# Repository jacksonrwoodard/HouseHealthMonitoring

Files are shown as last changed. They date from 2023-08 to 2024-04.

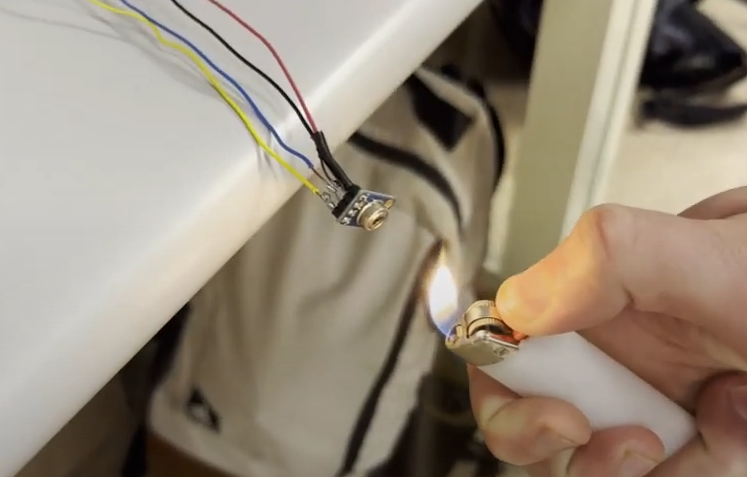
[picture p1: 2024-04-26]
Documentation/Images/Fire/Fire_Test_Open_Flame.jpg

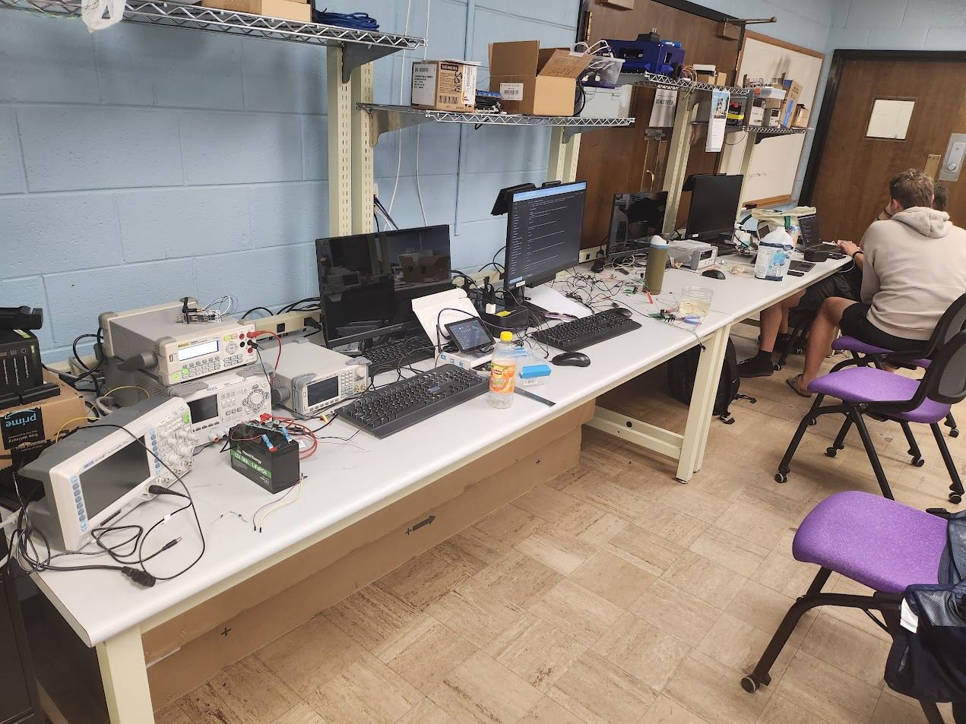
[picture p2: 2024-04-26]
Documentation/Images/Communication/Communication_Test_1.png

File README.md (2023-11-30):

# Preserve Home Pro (PHP)
## Executive Summary

Houses face many types of issues like gas leaks, fires, floods, and mold, which cause damage to the house leading to a decrease in value. Unlike a smartphone or a modern car, current house constructions lack a mechanism to detect and monitor this information. This information, such as knowing if water damage has occurred, could improve the value of the house by proving that issues have not occurred or were taken care of quickly by the homeowner. To detect and monitor all of these problems, this project proposes a collection of sensors and a head unit, called Preserve Home Pro. The goal of the system is to measure, record, and display important active and historical data, giving a homeowner valuable information to help maintain and protect the value of their home. The Preserve Home Pro will be designed as a semi-permanent system that will last for up to thirty years. The system will also communicate information through a closed network without requiring the Internet. Combining these concepts, this project proposes an advanced solution to house health monitoring.

## Capabilities

Detailed capabilities for this project are described in the [Signoffs](https://github.com/jacksonrwoodard/HouseHealthMonitoring/tree/main/Documentation/Signoffs) section of this repository. Each signoff includes the function of the subsystem, constraints, buildable schematics, analysis, and bill of materials. The following bullet points detail the current expectations of the house health monitoring system.
- The Head Unit subsystem expects to receive serial data from the communication receiver and implement a user friendly interface that displays historical and active data from each sensor module.
- The Communication subsystem will allow the sensors' microcontroller to send data wirelessly to the head unit's microcontroller through the Zigbee protocol.
- The Power subsystem will supply power functionality for each subsystem. Each subsystem will be hard-wired into the house with each sensor module having an uninteruptable power supply (UPS) to power them when the electricty in the home goes out. All head unit and communication functionality will be disabled while the power is out to ensure maximum battery lifetime.
- The Mold subsystem will read temperature and humidity levels at its respective sensor in order to detect if mold like conditions are present in a home.
- The Fire subsytem will read specific temperature levels to detect whether a fire is present or not in a room.
- The Gas subsystem will read parts per million (ppm) levels to determine if gas is present in a room and specifiy which gas it is.
- The Flood subsytem will read water levels based on resistivity to detect any amounts of water present in the area.
- Each sensor module will serially send data to a local microcontroller so that it can send the data to the head unit for computation and storage.

## Salient Outcomes

Projects often have some outcomes that are more interesting than others. Here, highlight those things that you found interesting!

(Coming Spring 2024!)

## Project Demonstration & Images

Give a link to a video of the project being demonstrated. The video should be hosted on the capstone youtube.

Below the video link show some well-taken, appropriately sized images of the project.

(Coming Spring 2024!)

## About Us

### Team

[Jackson Woodard](https://www.linkedin.com/in/jacksonrwoodard/) is currently pursuing a degree in Electrical Engineering with a minor in Computer Science at Tennessee Technological University. His academic focus lies in the field of Programmable Logic Controllers (PLC) and Control Systems. In the context of the project, Jackson has been assigned the responsibility of developing a Fire Module designed to detect potential fire occurrences within a designated space. He is also helping design the 3D models for all the subsystems for the project. 

[Cole Cooper](https://www.linkedin.com/in/cole-cooper-78063520b/) is a student of Electrical Engineering enrolled at Tennessee Technological University in Cookeville. He has an academic interest in following the development and sustainment of power systems, microcontrollers, and communication protocols to name a few. Cole's role in this project is the development of the head unit and the communications system between the head unit and the sensor modules.

[Dylan Robbins](https://www.linkedin.com/in/dylan-robbins-51b933256/) is a student currently pursuing a bachelor's degree in Computer Engineering at Tennessee Technological University. His academic interests are focused in Embedded Systems, microcontrollers, and computer programming. Dylan's role in the project is to develop a mold sensing module and design it to detect any mold like conditions in a home. He is also responsible in assisting in any programminng of the sensors and data computations for the system.

[Nate Campbell](https://www.linkedin.com/in/nathaniel-campbell-0b24a2225) is a dedicated Electrical Engineering student enrolled at Tennessee Technological University. His academic focus revolves around Power Systems and Programmable Logic Controllers (PLC). Within the current project, Nathaniel assumes a pivotal role, primarily concentrating on the water sensor aspect and actively contributing to the development of the Uninterruptible Power Supply (UPS) for the overall power system.

[Luke Carson](https://www.linkedin.com/in/luke-carson/) is an Electrical Engineering at Tennessee Technological University with a minor in Mathematics. His primary area of interest lies in power systems, including power generation, transmission, and distribution. As part of a project, Luke is responsible for designing the gas module for the Preserve Home Pro system. The module will be used to detect the presence of propane, carbon monoxide, and ammonia.

### Faculty Supervisor

[Jesse Roberts, M.S.](https://www.tntech.edu/directory/engineering/faculty/jesse-roberts.php) is a professor at Tennessee Technological University. He has received both a Bachelor's and Master's degree in Electrical Engineering at Tennessee Technological University. He is currently pursuing a Doctorate of Philosophy in Computer Science at Vanderbilt University.

### Stakeholders

The customer and major stakeholder for the project is any home owner wanting to monitor and maintain their home's health. This system can be installed in any pre-existing or newly built home to display active and historical data pertaining to the specific sensing modules. Home owners are majorly impacted by this system because this system will physically be installed into their home and will assist inspections of areas and things that might be hard to detect will human senses. One major internal stakeholder for this project is the project supervisor, Jesse Roberts. He has given a majority of the feedback to help further the design process. One major external stakeholder for this project is insurance companies, or more specifically, Wes Harris from State Farm. He has provided valuable feedback on how the project affects not only homeowners but also insurance agencies. With this house health monitoring system being installed into homes, home owners could potentially get discounts on their home insurance since issues will be detected before they are major issues as well as potentially raising the value of their home.

### Recognitions

The team would like to thank the ECE Department at Tennessee Technological University for all the assistance needed in the design process. The team would also like to thank Jesse Roberts for all the assistance that he has given throughout the entire Capstone Project. Finally, the team would like to thank one of the external stakeholders, Wes Harris from State Farm, for answering any questions and providing the team with useful information to further advance the project.

## Repo Organization

### [Reports](/Reports)

The [Project Propsal](https://github.com/jacksonrwoodard/HouseHealthMonitoring/blob/main/Reports/Project%20Proposal/Project%20Proposal%20V2.pdf) report provides information about what the project problem is and the proposed solution.

The [Conceptual Design and Planning](https://github.com/jacksonrwoodard/HouseHealthMonitoring/blob/main/Reports/Conceptual%20Design%20%26%20Planning/Conceptual%20Design%20Final.pdf) report provides all specifications and constraints that the House Health Monitoring project must follow. The report includes all standards and regulations that will be followed during the project.

The [Experimentation](/Reports/Experimentation) report includes (will be finished later)

The [Poster](/Reports/Poster) shows (will be finished later)

The [Final Report](/Reports/Final_Presentation) includes (will be finished later)

The [Lessons Learned](/Reports/Lessons_Learned_&_Acquired_Skills) files show the lessons the team learned throughout the project process. 

### [Documentation](/Documentation)

All documentation for the project is included in the folder listed above. There are folders for 3D Models, Electrical, Images, Meeting Minutes, and Signoffs. All folders can be found in the documentation folder. 

The [Signoffs](/Documentation/Signoffs) folder has all of the approved detailed designs. The designs met all specifications and constraints for each subsystem. 

The [Meeting Minutes](https://github.com/jacksonrwoodard/HouseHealthMonitoring/tree/main/Documentation/Meeting%20Minutes) folder contains detailed minutes for each team meeting that occurred throughout the project process. Reading these files will provide you will knowledge of how the team advanced week to week.

### Software

All software used in the project will be located in this directory. For each system, a folder will be created that contains the relevant code with a readme file explaining the process of installing, executing, and testing the code.

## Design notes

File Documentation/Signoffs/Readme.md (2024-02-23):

## Signoffs

Listed below are all of the team's completed signoffs:

- [Communication Signoff](https://github.com/jacksonrwoodard/HouseHealthMonitoring/blob/main/Documentation/Signoffs/php-communication-signoff.md)
- [Fire Module Signoff](https://github.com/jacksonrwoodard/HouseHealthMonitoring/blob/main/Documentation/Signoffs/jacksonwoodard-fire-signoff.md)
- [Mold Module Signoff](https://github.com/jacksonrwoodard/HouseHealthMonitoring/blob/main/Documentation/Signoffs/dylanrobbins-mold-signoff.md)
- [Headunit Module Signoff](https://github.com/jacksonrwoodard/HouseHealthMonitoring/blob/main/Documentation/Signoffs/php_headunit_signoff.md)
- [Gas Module Signoff](https://github.com/jacksonrwoodard/HouseHealthMonitoring/blob/main/Documentation/Signoffs/lukecarson-gas-signoff.md)
- [Flood Module Signoff](https://github.com/jacksonrwoodard/HouseHealthMonitoring/blob/main/Documentation/Signoffs/natecampbell-flood-signoff.md)
- [Power Module Signoff](https://github.com/jacksonrwoodard/HouseHealthMonitoring/blob/main/Documentation/Signoffs/colecooper-power-signoff.md)

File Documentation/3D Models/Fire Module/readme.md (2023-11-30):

# Fire Module 3D Model

Shown in this file is the completed and printable 3D Model of the enclosure that will be used for the Fire Module.

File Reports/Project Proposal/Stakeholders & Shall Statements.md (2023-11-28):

## Stakeholders
  - Interior Stakeholders
    - Project Team
    - Project Supervisor (Jesse Roberts)
    - Funding (ECE Department)

  - External Stakeholders
    - Home Owners
    - Landlords
    - Insurance Companies

## Shall Statements

1) The Head unit shall know what sensor is sending data to
it, the sensor’s location, and be able to differentiate from
other sensors. This originated from the team supervisor.
2) The Head unit shall be able to display and log active
and historical data from sensors. This originated from
the project team and team supervisor.
3) Head unit shall be able to detect if the fire module
temperature is at 176 degrees Fahrenheit or higher and
display a warning [4]. This originated from the project
team based on the ignition temperature of drywall.
4) The Head unit shall be able to receive data from the
water module to display a warning if water is present and
the total water depth. This originated from the project
team.
5) Head unit shall receive data from the gas module and
follow OSHA standards for ammonia, propane, and carbon oxides (50 ppm, 1000 ppm, and 50 ppm respectively
over an eight-hour window) [5]. This originated from the
OSHA standards for the project.
6) Head unit shall be able to interpret, from the received
data, that mold could form if the humidity levels exceed
50% and temperatures range between 55 degrees and 85
degrees Fahrenheit for a minimum of two days [6]. This
originated from the project team based on the conditions
in which mold can grow.
7) Head unit shall be able to receive the sensor name,
number, data type, and raw data. This originated from
the team supervisor.
8) System shall be primarily powered from the house’s 120
V power supply. This originated from the project team.
9) Shall be a semi-permanent system that will last for up to
thirty years. This originated from the team supervisor.
10) Shall have a backup power system that will allow the
system to function in case of a primary power outage
for up to two continuous weeks. This originated from
both a standard and the team supervisor.
11) Shall fully function without regularly changing sensors
or head unit batteries. This originated from all external
stakeholders and the team supervisor.
12) Sensor modules shall not be placed in a way where they
cannot wirelessly communicate with the system. This
originated from the project team and broader implications.
13) Modules shall not be a distraction for a homeowner, and
not be directly visible. This originated from all external
stakeholders and the team supervisor.
14) The Water module shall be able to detect multiple water
levels and determine if water is present. This originated
from the project team.
15) The Mold module shall be able to detect the current
temperatures and humidity levels in an area and send it
to the head unit. This originated from the project team.
16) The Gas module shall be able to detect ammonia,
propane, and carbon oxide. This originated from the
project team and the insurance companies.
17) The Fire module shall be able to detect the temperature
of the sensor and send the data to the head unit. This
originated from the project team.
18) System shall not require an internet connection to work
and communicate with the head unit and sensors. This
originated from homeowners, insurance agencies, and
the team supervisor.
19) Sensor communication shall send the sensor name, number, data type, and raw data to the head unit. This
originated from the project team.
20) System shall not collect additional data that is not
required for sensor functionality. This originated from
all internal and external stakeholders and from broader
implications.
21) System shall follow all IEEE Code of Ethics and common standards. This originated from the IEEE Code of
Ethics.

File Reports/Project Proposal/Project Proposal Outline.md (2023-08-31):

Project Proposal Outline
================================

- Abstract (Elevator Pitch)
- Keywords

## Introduction
- Objective/Goal
- Why is this important?
- Solution

## Formulating the Problem
- Background Information
  - Includes head unit & all 5 types of sensors we plan to use
    - Flood Sensor (Nate)
    - Mold/Moisture Sensor (Dylan)
    - Heat/Fire Sensor (Jackson)
    - Gas/Smoke Sensor (Luke)
    - Electrical Sensor (Cole)
    - Termite Sensor?
- Constrants & Specifications
  - Standards
  - External Effects on Life
- Discovered Solutions
  - Hardware & why we are going to use it
  - Researching solutions that have already been solved
- Summerizing the Problem
   - What makes the project different/better from other solutions?
  
## Proposed Solution
  - Unknowns, Obstacles, Implications, and Necessary Experiments
  - Measurements of Success
    - Explain experiments that we are going to do and what we will classify it as a success.
  - Responsibiliies as an Engineer

## Resources
  - Budget Proposal
  - Sofware, equipment, materials
  - Personnel
  - Timeline
    - Gantt Chart
   
## Refrences

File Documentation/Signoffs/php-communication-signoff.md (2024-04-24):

# Communication Module Signoff

## Subsystem Function
The function of the communication subsystem is to act as a transmitter for each of the sensor modules and a receiver for the head unit. The function of the transmitter is to send the sensor name, data type, sensor number, and sensor data. The function of the receiver is to receive all of the data from the sensor modules and make the received information available to the processor. 

TransmitterCommunication

RecieverCommunication

## Constraints
| No. | Constraints | Origin |
| --- | --- | --- |
|  1  | System shall not require an internet connection to work and communicate with the head unit and sensors | Home Owners, Insurance Agencies, & Team Supervisor |
|  2  | At least one sensor shall be placed within 200ft of the head unit. | Project Team |
|  3  | Sensors shall be within 32ft from each other for every sensor outside of 200ft of the head unit. | Project Team |
|  4  | Sensor communication shall send the sensor name, number, data type, and raw data to the head unit. | Project Team |
|  5  | ESP32 shall be able to send a minimum of 128 bits (2 packets) at a transmission rate of at most 250 Kbps on a 2.4 GHz frequency. | Project Team & Standards|
|  6  | The head unit shall, at minimum, receive data every 24 hours, when the data from the sensor reaches a critical level, or when the user requests the data. | Project Team |

<sup>1</sup> In order for the system to not require an internet connection, the system will be designed to work on a Personal Area Network (PAN). In order to achieve this, the Zigbee communication protocol will be used.

<sup>2</sup> In order for the system to work properly all of the sensors have to be able to communicate with the head unit. At least one sensor has to be within 200ft of the head unit because the XB24's maximum range allows for 200ft of indoor communication. Indoor means through the interior walls of a house.

<sup>3</sup> The sensors have to be placed within 32ft of each other for the minimum transmission and reception range of the Zigbee-compliant devices.

<sup>4</sup> The head unit needs to know the sensor information to be able to organize the data of each sensor. Knowing this allows the information to be more easily displayed to the user.

<sup>5</sup> In order to meet Zigbee specifications and IEEE 802.15.4 standards, it is required to have a transmission rate of at most 250 Kbps on a 2.4 GHz frequency. Zigbee networks are secured by 128-bit symmetric encryption to meet Zigbee specifications, so 128 bits have to be sent to the head unit per transmission.

<sup>6</sup> In order to save power, the system is designed to only send data to the head unit at least once every 24 hours. The ESP32-H2 will store the data received from the sensor and send the stored data to the head unit when requested or when the data has reached the specific limit that causes a threat. The user will have the option to request for the data and if the data is requested the ESP32 will send the data over to the head unit for the user to see. With this constraint, power will be saved significantly allowing the system to have the ability to work off of battery power for a minimum of two weeks.

## Buildable Schematic
#### Head Unit Reciever from Manufacturer
Reciever

The picture shown above is the XB24CAWIT-001, the schematic shows an in-depth design of the receiver.
#### Sensor Module Transmitters from Manufacturer
 Transmitter
 
The picture shown above is the ESP32-H2, the schematic shows an in-depth design of the transmitter.

#### Third-Party Buildable Schematic

CommunicationSchematic

This is a third-party buildable schematic to show connections and communications from the sensor modules and the head unit. The pins labeled DOUT (TX) and DIN (RX) on the XB24 are the UART pins [4]. The XB24 will use these pins to transmit and receive information to and from the head unit using serial UART communication [4]. The ESP32-H2 has many peripherals that can be used through most of the GPIO pins [1]. The use of these GPIO pins will vary from sensor to sensor depending on the required pinouts to serially send and receive information between the ESP32-H2 and sensor. Communication between each ESP32-H2 and the XB24 will be wireless using and following Zigbee protocols.

## Analysis

<sup>1</sup> The ESP32-H2 is able to communicate via Zigbee protocols [1]. Zigbee protocols allow for the formation of a mesh network, allowing the system the work for any size house without an existing internet connection [2]. The ESP32-H2 has a built-in 2.4 GHz receiver and transmitter that will form a mesh network to ensure that all sensors will be able to communicate with the head unit [1]. Zigbee is designed to create a personal area network (PAN), which would not require the system to have to connect to an internet connection [3]. Zigbee devices are either preconfigured with a PAN ID to join, or they can discover nearby networks and select a PAN ID network to join [3]. This allows any Zigbee device to connect to each other as long as the PAN ID is in a discoverable range. 

<sup>2</sup> The head unit is not able to communicate with Zigbee devices natively, so a Zigbee-capable transmitter and receiver are necessary for proper function. The XB24 is able to communicate via Zigbee protocols [4]. This Zigbee module allows direct connectivity to an Arduino or related board. It will also allow the system to extend its range up to 200ft indoors, giving it the ability to reach the sensors in a house [4]. If a sensor is placed outside of the 200ft range, then a mesh network would be incorporated into that system.

<sup>3</sup> The ESP32-H2 has the capability to transmit data at a minimum of 32ft [5]. For a mesh network to be created, there must be a sensor within 200ft of the head unit and a sensor within 32ft of that sensor. So, as long as each sensor module is placed within 32ft of one another, a mesh network can be used [5]. 

<sup>4</sup> Zigbee protocol requires a minimum of 128 bits to be sent during transmission [2]. Each sensor module will have a unique 16-bit PAN ID allowing the information to be differentiated from one another [3]. The PAN ID will be sent to the head unit allowing it to act as an identifier to determine which sensor is sending data. The remaining 112 bits of the transmission will be used for the data type, raw data, and encryption. All of the sensors being used will not require more than 24 bits to send the raw data, so with the amount of remaining bits, this would be possible. The data type will also not require more than 24 bits, so this would be possible. This information will be used for showing the live and stored data from the modules. 

<sup>5</sup> According to the ESP32-H2 datasheet, the ESP32-H2 is designed to follow all Zigbee specifications [1]. This means that the ESP32-H2 will be able to send a minimum of 128 bits (2 packets) at a transmission rate of at most 250 Kbps on a 2.4 GHz frequency. Each module has 320 kB SRAM, meaning each module can hold up to 2,621,440 bits in a given moment for local storage and transmission information. In a setting of 100 sensor modules if a singular module held onto the transmission data from each module would take up 12800 bits leaving 2,608,640 bits free in the ESP32 H2’s SRAM for other operations like continual data reading from the attached sensor. The ESP32 H2 will be sufficient for receiving all communications from other devices in the network.

<sup>6</sup> In order to preserve power, the ESP32 will store the data that the sensors read and send the data to the head unit every 24 hours. The ESP32 uses significantly more power to transmit or receive data than just reading data from the sensor. Opting to store data on the ESP32 and send it to the head unit every 24 hours, will cut down power consumption allowing for the 30-year life expectancy. The head unit will still receive all sensor reading data, but it will only send the data, at minimum, once every 24 hours to reduce power consumption. The ESP32 will also send the data to the head unit if the sensor data reaches the critical level that is specified in the code on the ESP32. The critical level will depend on each separate sensor module. The head unit will have the ability for the user to request the current data from the sensors. If the user requests the data, the ESP32 will send the data that is currently stored on the ESP32 to the head unit, showing the user the active data. The largest amount of data that any sensor module will use is 1 packet because each sensor has a unique 16-bit PAN ID and data reading will not need more than 48 bits with the sensors that are being used in the system. The ESP32 has 4MB ROM of storage allowing it to store the sensor module data for up to 24 hours [5]. There are 32,000,000 bits in 4MB, and at 64 bits per packet, each ESP can store 500,000 readings at a time. There are 86,400 seconds in 24 hours, so if the sensors were to store data every second in a 24-hour period, this would still be possible.

## Bill of Materials (BOM)
| DEVICE | Quantity | Price Per Unit | Total Price | Overall Total |
| --- | --- | --- | --- | ----- |
| ESP32-H2-DEVKITM-1-N4 | 3 | $10.00 | $30.00 | |
| SONOFF Zigbee 3.0 USB Dongle Plus | 1 | $21.99 | $21.99 | $51.99 |

## References
[1] Espressif Systems, “ESP32-H2 - Espressif Systems,” Adafruit, https://www.espressif.com/sites/default/files/documentation/esp32-h2_datasheet_en.pdf (accessed Oct. 24, 2023). 

[2] “Discover Zigbee protocol 3.0,” Discover Zigbee Protocol 3.0 | Digi International, https://www.digi.com/solutions/by-technology/zigbee-wireless-standard (accessed Oct. 24, 2023). 

[3] “PAN ID,” Pan Id, https://www.digi.com/resources/documentation/Digidocs/90002002/Concepts/c_zb_pan_id.htm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,devices%20of%20the%20same%20network. (accessed Oct. 25, 2023). 

[4] “Digi xbee S2C 802.15.4 RF modules Datasheet,” IIoT Devices and Services for M2M Networking, https://www.digi.com/resources/library/data-sheets/ds_xbee-s2c-802-15-4?view=fullscreen (accessed Oct. 24, 2023). 

[5] Reolink, “Zigbee range: You must know the truth,” Reolink, https://reolink.com/blog/zigbee-range/ (accessed Oct. 25, 2023).

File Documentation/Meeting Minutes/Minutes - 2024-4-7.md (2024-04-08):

Opening
The team meeting of Capstone I Team 4 was held at 1:00 PM on April 1, 2024 in Brown Hall in room 408.

Present
Cole Cooper, Secretary
Dylan Robbins, Team Member
Jackson Woodard, Team Lead
Luke Carson, Team Member
Nate Campbell, Team Member

Approval of Agenda
This meeting was approved by Jackson Woodard.

Business From Previous Meeting
The first order of business is the continuation of work on additional module communication with the head-unit.

The next order of business is comparing the existing function of the overall system with the determined success and constraint metrics.

New Business 
No new business this week.

Additions to the Agenda
Each member is determining and preparing their measures of success and experimentation.

Jackson is continuing to add more wireless communication between sensor modules and the headunit. 

Nate has figured out how to allow for analog pin readouts to be read and transferred wirelessly to the head-unit. 

Luke is working on re-configuring Nate’s code to work with the gas sensor. 

Dylan and Jackson are compiling a code in order to get the temperature sensors from the mold and fire modules functioning. 
Cole is working on setting up the initial documentation for experimentation in the github. 

Agenda for Next Meeting
The first order of business is the continuation of work on additional module communication with the head-unit.

The next order of business is comparing the existing function of the overall system with the determined success and constraint metrics.

Adjournment 
Meeting was adjourned at 3:00 PM by Jackson Woodard. With planning of meeting again on April 15, 2024 at 1:00 PM.

Minutes Submitted by: Cole Cooper
Approved by: Jackson Woodard

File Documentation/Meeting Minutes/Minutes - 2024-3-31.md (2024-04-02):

Opening
The team meeting of Capstone I Team 4 was held at 1:00 PM on April 1, 2024 in Brown Hall in room 408.

Present
Cole Cooper, Secretary
Dylan Robbins, Team Member
Jackson Woodard, Team Lead
Nate Campbell, Team Member

Absent
Luke Carson, Team Member

Approval of Agenda
This meeting was approved by Jackson Woodard.

Business From Previous Meeting
Finish any additional sections of additional functionality needed.

New Business 
No new business this week.

Additions to the Agenda
Cole, Dylan, and Luke were able to successfully set the headunit to be able to receive and display the information generated by the sensor modules.

Jackson and Nate are fine tuning a new code to allow for more sensor-modules to head-unit communication. This step has been extremely time intensive due to a lack of example ESP32 H2 example codes. This lack of example codes is most likely due to the ESP32 H2 being so new to the market. 

Agenda for Next Meeting
The first order of business is the continuation of work on additional module communication with the head-unit.

The next order of business is comparing the existing function of the overall system with the determined success and constraint metrics.

Adjournment 
Meeting was adjourned at 3:00 PM by Jackson Woodard. With planning of meeting again on April 8, 2024 at 1:00 PM.

Minutes Submitted by: Cole Cooper
Approved by: Jackson Woodard

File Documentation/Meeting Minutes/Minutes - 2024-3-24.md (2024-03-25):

Opening
The team meeting of Capstone I Team 4 was held at 1:00 PM on March 18, 2024 in Brown Hall in room 408.

Present
No meeting was held this week

Absent
Luke Carson, Team Member
Cole Cooper, Secretary
Dylan Robbins, Team Member
Jackson Woodard, Team Lead
Nate Campbell, Team Member

Approval of Agenda
This meeting was approved by Jackson Woodard.

Business From Previous Meeting
Finish any additional sections of additional functionality needed.

New Business 
No new business this week.

Additions to the Agenda
Cole and Jackson are working on setting up the head-unit to allow for the head-unit to receive and display information from the sensor-modules. As of current, the head-unit has only been able to receive the information, but another computer was needed for reading the received information.

Dylan, Luke and Nate are working on compiling and testing a new code in order to allow for more sensor-modules to head-unit communication.

Agenda for Next Meeting
The first order of business is the continuation of work on additional module communication with the head-unit.

The second order of business is finishing the head-unit’s receive and display functionality.

The final order of business is comparing the existing function of the overall system with the determined success and constraint metrics.

Adjournment 
Meeting was adjourned at 3:00 PM by Jackson Woodard. With planning of meeting again on March 25, 2024 at 1:00 PM.

Minutes Submitted by: Cole Cooper
Approved by: Jackson Woodard

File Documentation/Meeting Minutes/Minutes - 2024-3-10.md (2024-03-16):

Opening
The team meeting of Capstone I Team 4 was held at 1:00 PM on March 4, 2024 in Brown Hall in room 408.

Present
No meeting was held this week

Absent
Luke Carson, Team Member
Cole Cooper, Secretary
Dylan Robbins, Team Member
Jackson Woodard, Team Lead
Nate Campbell, Team Member

Approval of Agenda
This meeting was approved by Jackson Woodard.

Business From Previous Meeting
Finish any additional sections of additional functionality needed.

New Business 
No new business this week.

Additions to the Agenda
Cole has ordered a new USB antenna for use as a receiver from the modules. The XBee s2c was not communicating with the head unit resulting in a new device needed.

Jackson, Dylan, Nate, and Luke are continuing the conversion of code from Arduino’s ESP IDE to Espressif’s ESP IDE. Espressif is the manufacturer of the ESP devices and we have found that wireless communication works better using the Espressif IDE.

Agenda for Next Meeting
Finish any additional sections of additional functionality needed.

Adjournment 
Meeting was adjourned at 6:00 PM by Jackson Woodard. With planning of meeting again on March 18, 2024 at 1:00 PM.

Minutes Submitted by: Cole Cooper
Approved by: Jackson Woodard

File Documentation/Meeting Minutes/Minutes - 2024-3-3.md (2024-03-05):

Opening
The team meeting of Capstone I Team 4 was held at 1:00 PM on March 4, 2024 in Brown Hall in room 408.

Present
Luke Carson, Team Member
Cole Cooper, Secretary
Dylan Robbins, Team Member
Jackson Woodard, Team Lead

Absent
Nate Campbell, Team Member

Approval of Agenda
No new agenda was added for this meeting

Business From Previous Meeting
Dylan has started working on the code to get the mold module to function. This code is not functioning yet. We believe his code will be similar to Jackson’s.

Jackson has started working on the code to get the fire module to function. Through initial attempts this code is functioning with a few errors.

Nate has started working on the code to get the water module to function. This code is functioning and the water sensor is reading and outputting values as expected.

Luke has started working on the code to get the gas module to function. This code is not functioning yet. We believe his code will be similar to Nate’s.

Cole is starting on the setup for the head unit to be able to communicate and store data read from each module.

New Business 
Jackson will record the fire module’s sensor reading accurate temperatures to prove minimal functionality.

Dylan will record the mold module’s temperature and humidity sensor functioning correctly to prove minimal functionality.

Luke will record the gas module’s sensor reading voltage changes from the gas parts per million to prove minimal functionality.

Nate will record the water module’s sensor reading voltage changes from water being in contact with the sensor.

Additions to the Agenda
No additions this week.

Agenda for Next Meeting
Finish any additional sections of additional functionality needed.

Adjournment 
Meeting was adjourned at 6:00 PM by Jackson Woodard. With planning of meeting again on March 11, 2024 at 1:00 PM.

Minutes Submitted by: Cole Cooper
Approved by: Jackson Woodard

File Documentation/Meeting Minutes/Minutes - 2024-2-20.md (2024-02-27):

Opening
The team meeting of Capstone I Team 4 was held at 1:00 PM on February 20, 2024 in Brown Hall in room 408.

Present
Nate Campbell, Team Member
Luke Carson, Team Member
Cole Cooper, Secretary
Dylan Robbins, Team Member
Jackson Woodard, Team Lead

Absent
All members present

Approval of Agenda
No new agenda was added for this meeting

Business From Previous Meeting
Luke was able to add the schematic updates to the gas module in order to get it signed off.

Cole got feedback from Dr. Bhattacharya about what battery type and charging circuit would be best fit for the project. The battery type mentioned is a Lithium Iron Phosphate battery, while the recommended charging circuit is a voltage divider trickle charger. This type of battery will allow for 10 years of use with instant power swap over for continual usage of the sensor modules. 

New Business 
Dylan has started working on the code to get the mold module to function. This code is not functioning yet. We believe his code will be similar to Jackson’s.

Jackson has started working on the code to get the fire module to function. Through initial attempts this code is functioning with a few errors.

Nate has started working on the code to get the water module to function. This code is functioning and the water sensor is reading and outputting values as expected.

Luke has started working on the code to get the gas module to function. This code is not functioning yet. We believe his code will be similar to Nate’s.

Cole is starting on the setup for the head unit to be able to communicate and store data read from each module.

Additions to the Agenda
Cole was able to add the information learned from Dr. Bhattacharya to update the power module in order to get it signed off.

Agenda for Next Meeting
Start team discussion of minimal functionality of this project.

Adjournment 
Meeting was adjourned at 6:00 PM by Jackson Woodard. With planning of meeting again on February 27, 2024 at 1:00 PM.

Minutes Submitted by: Cole Cooper
Approved by: Jackson Woodard

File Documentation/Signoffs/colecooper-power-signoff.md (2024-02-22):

# Power Module Signoff

## Subsystem Function
The power system allows the sensor modules to function properly on power from a house and in case of power outages. In order to safely and reliably maintain the funcion of the sensors, the use of an uninteruptable power supply (UPS) is also necessary.

## Constraints
| No. | Constraints | Origin |
| --- | --- | --- |
|  1  | System shall be primarily powered from the house's 120 Volt power supply. | Project Team |
|  2  | Shall have a backup power system that will allow the system to function in case of primary power outage for up to two continuous weeks. | Project Team & Team Supervisor |
|  3  | Shall fully function without regularly changing sensors or head unit batteries. | All External Stakeholders, & Team Supervisor |

<sup>1</sup> The standard residential voltage is 120 V power in the United States. The power module will need to work with the North American standard in order for the sensor modules and head units to have reliable power access.

<sup>2</sup> The sensor modules should still be functional even when the primary power source is out. In the United States the year of 2021 had multiple record breaking power outages lasting up to two weeks. The modules should still be able to record information while the power is out. 

<sup>3</sup> The ESPs and sensors will be powered through the UPS while the main power source is out, to allow for minimal functionality, until it kicks back on. The UPS will include a charging circuit so that the same batteries can stay in place and be recharged.

## Buildable Schematic
 UPS Circuit Diagram

The power comes from the 15V 2A wall wart that goes through a diode to prevent the eletricity from the battery pack from feeding back into the wall power. The 1 kOhm resistor is used to reduce the amount of amperage that will go to the battery pack allowing for the battery to be charged slowly and not over charge the battery. The other diode is used to provide a low resistance path between the voltage regulator and the battery pack. This enables the ESP32 to be powered if the voltage drops too low. The voltage regulator is used to step down the voltage to output exactly 5V into the ESP32 [1].

## Simulations
UPS Circuit Design (LTSpice)
LTSpice Wall Power Vin
LTSpice Wall Power Vout

The three pictures shown above are the LTSpice simulations showing the voltage going into the voltage regualtor and the voltage going out of the voltage regulator when there is power in the house.

UPS Circuit Design (LTSpice) 0V Wall Power
LTSpice Battery Power Vin
LTSpice Wall Power Vout

The three pictures shown above are the LTSpice simulations showing the voltage going into the voltage regualtor and the voltage going out of the voltage regulator when there is no power in the house.

## Analysis
<sup>1</sup> The Raspberry Pi 4B and the ESP32 H2 DEVKITM-1 both use 5 volt power in for proper operation. The Raspberry Pi 4 power supply is a transformer that converts the 120V AC down to the needed 5V DC to make the microcontrollers work properly. 

<sup>2</sup> The team is creating an uninterruptible power supply (UPS) using diodes, a voltage regulator, a resistor, a 12.8V 9Ah battery, and a 120V AC to 14.6V DC transformer. The circuit diagram shown above is a voltage divider [1]. In a conversation with Dr. Bhattacharya, he said “for charging your system, a voltage or current divider would be the best system.” Using a LiFePO4 battery that has a BMS will prevent over charging from this voltage divider circuit. When running the ESP32-H2 and one sensor, the minimum amount of amp hours needed is 6216 mAh for two weeks. The battery that has been chosen operates at 9Ah which is greater than the 6.216 Ah (6216 mAh) needed, so the system will be able to operate for a minimum of two weeks with the chosen battery. The UPS is designed to charge the battery when the power is on, and when the power is off the battery will be powering the ESP32 and the sensor. 

<sup>3</sup>  After discussion with Dr. Bhattacharya, there is no type of battery that can last for a 30 year life span for our use case. The type of battery that Dr. Bhattacharya recommended is the lithium iron phosphate (LiFePO4) battery. The deep cycle LiFePO4 batteries have a 10 year service life with 2,000+ cycles. The battery we have specified has around 4,000 cycles which is a full charge and discharge each day for over 10 years. The 12.8V 9Ah battery has the power to let the system fully function without the need of standard wall power for over the two-week period needed. The UPS will recharge the battery when the power is on, allowing the backup batteries to have full charge for any time the wall power is lost. The 12.8V 9Ah battery is a LiFePO4, which is being used for longer life span compared to other rechargeable batteries, higher safety factor, and improved discharge and charge efficiency thanks to its integrated battery management system (BMS) [2]. LiFePO4 batteries, like the one we are using, come with a battery management (BMS) that protects the cells within the battery pack from overcharge voltages over 14.6 V DC, over discharge, shorts, over currents, and high temperatures. The BMS and low cycle rate will help ensure this battery stays functional for its full 10 year service life.

## Bill of Materials (BOM)
| DEVICE | PART NUMBER | Quantity | Price Per Unit | Total Price |
| --- | --- | --- | --- | --- |
| Raspberry Pi 4 Power Supply | SC0214 | 3 | $8.00 | $32.00 |
| 14.6V LiFePO4 Battery Charger | TP-30W-1462000 | 1 | $13.59 | $13.59 |
| 1N4001 Diode Pack | 1N4001 | 1 | $4.07 | $4.07 |
| 12.8V 9Ah LiFePO4 Lithium Battery | 3164-PSL-SC-1290F2-ND | 1 | $37.99 | $37.99 |
| L7805CV Voltage Regulator | L7805 | 1 | $8.59 | $8.59 |

## References
[1] J. Smith, “Create your own battery backup power supplies - projects,” All About Circuits, https://www.allaboutcircuits.com/projects/battery-backup-power-supplies/ (accessed Feb. 5, 2024).

[2] SuperB, “The lithium difference,” Benefits of Lithium Iron Phosphate batteries (LiFePO4), https://www.super-b.com/en/lithium-iron-phosphate-batteries/benefits-lithium-batteries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,you%20can%20make%20over%20time. (accessed Feb. 19, 2024).

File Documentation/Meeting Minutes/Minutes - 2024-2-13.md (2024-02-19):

Opening
The team meeting of Capstone I Team 4 was held at 1:00 PM on February 12, 2024 in Brown Hall in room 408.

Present
Nate Campbell, Team Member
Luke Carson, Team Member
Cole Cooper, Secretary
Dylan Robbins, Team Member
Jackson Woodard, Team Lead

Absent
All members present

Approval of Agenda
No new agenda was added for this meeting

Business From Previous Meeting
Cole will reach out to Dr. Bhattacharya over more specific information on batteries that can be used. 

Luke needs to add updates to the schematic to show where the filter that prevents significant interference will go. 

New Business 
No new business was added in this meeting

Additions to the Agenda
Luke was able to add the schematic updates to the gas module in order to get it signed off.

Cole got feedback from Dr. Bhattacharya about what battery type and charging circuit would be best fit for the project. The battery type mentioned is a Lithium Iron Phosphate battery, while the recommended charging circuit is a voltage divider trickle charger. This type of battery will allow for 10 years of use with instant power swap over for continual usage of our sensor modules. 

Agenda for Next Meeting
Start team discussion of minimal functionality of this project.

Adjournment 
Meeting was adjourned at 6:00 PM by Jackson Woodard. With planning of meeting again on February 19, 2024 at 1:00 PM.

Minutes Submitted by: Cole Cooper
Approved by: Jackson Woodard

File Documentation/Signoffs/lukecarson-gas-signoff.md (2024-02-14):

# Gas Module Signoff

## Subsystem Function
The gas module detects three gases that can be found in homes: propane, carbon monoxide, and ammonia. The module collects data on gas concentrations and wirelessly transmits it to the head unit through our wireless communication module. At the head unit, the data undergoes analysis to ensure compliance with OSHA standards for an eight-hour monitoring window. This process provides real-time data and alerts about gas concentrations, helping the system respond to and manage safety or environmental concerns.

Gas Module Block diagram

## Constraints
| No. | Constraints | Origin |
| --- | --- | --- |
|  1  | The Gas module shall be able to detect ammonia, propane, and carbon oxide. | Project  Team, Insurance Agencies|
|  2  | Head unit shall receive data from the gas module and follow OSHA standards for ammonia, propane, and carbon oxides (50 ppm, 1000 ppm, and 50 ppm respectively over an eight-hour window)| OSHA |
|  3  | The Gas module shall send data to headunit every second if the targeted gases are detected | Project Team |
|  4  | The Gas module shall be installed in a central location outside each sleeping area or in the immediate vicinity of the bedrooms, at the maximum of 20 feet | NFPA |
|  5  | The Gas module shall be placed as close as possible to potential gas leak spots | Project Team, Existing Products |
|  6  | The Gas module shall be orientated to where the target gas vapours tend to rise or fall | Project Team, Existing Produts |
|  7  | The Gas module shall not be placed near entrances/disturbances or fresh air vents where concentrations can be diluted | Project Team, Existing Products |
|  8  | The Gas module shall not be placed in bathrooms, garages, kitchens, furnace rooms, extremely dusty or dirty areas | Project Team, Existing Products |
|  9  | The Gas module shall not be placed in areas of the house enviroment where it is colder than -10°C or hotter than 50°C | Manufacturer |
|  10  | The Gas module shall not be placed in areas of the house enviroment where the humidity is more than 95% | Manufacturer |
|  11  | The Gas module shall be protected from unwanted variation of sensor readings due to noise | Project Team |

<sup>1</sup> Preserve Home Pro aims to detect three specific gases commonly known for causing poisoning at home. [1]

<sup>2</sup> To comply with OSHA standards, the gas concentrations monitored by Preserve Home Pro will be checked for an eight-hour period. [2]

<sup>3</sup> Preserve Home Pro will ensure fast response times if there is a adequate amount of gas presence specified in the other constraints in order to prevent harmful effects to the customer.

<sup>4</sup> Preserve Home Pro will follow the guidelines specified in the fourth constraint as per the NFPA standards. [3-4]

<sup>5</sup> To maximize the potential in detecting gas leaks, the gas module will be installed where gas piping is being fed into. [5]

<sup>6</sup> The targeted gases will be placed either near the ceiling or near the floor since each gas is either heavier or lighter than air and flows up or down. [5]

<sup>7</sup> Based on existing product installation manuals, Preserve Home Pro will avoid placing gas sensors in areas where there is a potential disturbance that could affect sensor detection. [3-5]

<sup>8</sup> Based on existing product installation manuals, Preserve Home Pro will avoid placing sensors in environments where there is a likelihood of false positives from other sources. [4]

<sup>9</sup> To meet the manufacturer's work environment, the sensors will not be placed within the specified temperature range.in order to keep functionality for constraints 9 and 10. [6-7]

<sup>10</sup> In order to provide reliable, accurate, and usable data the team will need to implement filtering in order to provide stable sensor readings. [16]

## Buildable Schematic  



Figure 1. This is the schematic of the MQ-9 sensor that is being used on the SRAQ-G014, this sensor targets propane and carbon monoxide. [9]



Figure 2. This is the schematic of the MQ-135 sensor that is being used on the SRAQ-G016, this sensor targets ammonia. [8]

#### Third-Party Buildable Schematic


Figure 3. This the wiring schematic of how the gas sensors will be connected to the each respective ESP32-H2, with the RC Filter in place.

## Analysis

<sup>1</sup> To meet constraints 1 and 2, there will be a need for two sensors to detect the gases Preserve Home Pro is targeting. The SRAQ-G014 will detect the presence and concentration of flammable gases (Propane) and carbon monoxide. The device features the MQ-9 sensing element that is highly sensitive to propane and carbon monoxide and has a detection range of 50-10000 ppm for propane and 10-1000 ppm for carbon monoxide.[6] The SRAQ-G016 is like the SRAQ-G014 but features the MQ-135 sensor whose elements are highly sensitive to ammonia and the detection range is from 10-1000ppm.[7] These ranges are crucial to meet the standards set by OSHA for the eight-hour monitoring window.

The gas module technical parameters show that the module will need a one-time 24-48 hour burn-in time for the sensors to be correctly calibrated and accurate. After that, the pre-heat time will be 30 minutes for the gas module to be calibrated and then the sensor will start collecting accurate data and be checked every second.[6-7]

Since the gas module detects and measures the concentrations of the specified gas ranges using analog voltage levels (within 0-5V), the analog output pins from the gas module will be connected to a 12-bit ADC pin on the ESP32-H2 so the microcontroller can collect and process into meaningful concentration data.[13] The ESP ADC takes data from the range of 0-3.3V, this means Preserve Home Pro will have to incorporate of voltage divider with the gas sensors in order to bring the voltage levels down from 5V to 3.3V in order to record accurate data and not lose any.

Now knowing this, we can use the binary base equation **2<sup>n</sup>**, where n is the number of bits the ADC is using which is 12 bits.[13] From the equation below, the ADC provides 4,096 discrete values within the 0-3.3V range, enabling fine voltage distinctions required for the calculation of ppm measurements. [13-15]

```math
Resolution = 2^n = 2^{12} = 4,096 steps
```

To be able to detect the smallest step size in ppm the ADC provides 4,096 unique values and Preserve Home Pro needs to detect the ppm range of 10-10000ppm for the gas targets.[6-7] [13] 

From the equation below, we can calculate smallest possible difference in values that can be measured compared to a scale of 10 to 10,000. This is calculated by dividing 9,990 (or the range between 10-10,000ppm) by the number of steps, or 9,990/steps. [15]

```math
Smallest-step = \frac{(Maximum-ppm)} {(Resolution)} = \frac{(9,990)} {(4,096)} = 2.439 ppm/step
```

<sup>2</sup> For constraint 3, the sensor will be connected to the communication module powered by an ESP32 microcontroller. As stated in the communication sign-off, the microcontroller has a transmission rate of 250 Kbps and sends two packets of data at a time. The sensor will will output a max value of 4096 or 12 bits when converted. Even with the PAN ID and data type as mentioned in the communication module, one sensor reading will not take up the full 128 bits in the two-packet transmission. Since the ESP32 can send at a 250 Kbps rate, one reading will take less than a second to reach the head unit.

<sup>3</sup> To meet constraint 4, Preserve Home Pro will be mounting the gas module no further than 20 feet from a location that is central to the surrounding vicinities of bedrooms. This is a requirement that NFPA has set on carbon monoxide detectors and will be addressed. Also, from already existing carbon monoxide alarms, the installation manuals address that if a home has a bedroom hallway of 40 feet then a module will be needed at each end to make up for 40 feet. [3] [4]

<sup>4</sup> For constraints 5 through 8, Preserve Home Pro looked at existing solutions from gas sensor manufacturers and developers to best suit the location of the gas module. The consensus for constraints 4 and 5 was to place the modules where leaks are prevalent or where gas sources are prone to leak.[5] This would include piping from gas sources to appliances (if homeowners have that feature for their house) so that Preserve Home Pro could detect propane accurately. The module for propane detection needs to be placed near the floor because propane is heavier than air and will naturally flow to the floor. [5] [11] The carbon monoxide spreads evenly through the air, and its location was addressed previously, so Preserve Home Pro must meet that location. [3-4] [10] Ammonia is lighter than air and will naturally want to float upwards, so the module will be placed near ceilings to be in the environment where ammonia resides. [12] For constraints 6 and 7, our selection of location will be the best place to conduct accurate readings without external environments affecting them. [3-5]

<sup>5</sup> According to the manufacturer's datasheet, Preserve Home Pro needs to meet constraints 9 and 10 to provide suitable work environments for the sensor. If the constraints are not met, the sensor will not function correctly and may potentially cause harm to homeowners. [6-7]

<sup>6</sup> Lastly for constraint 11, anytime when sensor measurements are taking place that data needs to be accurate and reliable. Preserve Home Pro has addressed the concerning attention of noise interference in the area of the system. A LTspice simulation was conducted in order to model the environment of our system and be able to verify the noise implemented on the system and to make sure the noise is not affecting the data involving measurements.

## Noise Simulation


Figure 4.The LTspice circuit of two coupled parallel wires next to each other.

From the figure above, this is modeling the system with wall power wires running next to the sensor wiring. The circuit on the left is the AC wiring of the house with 120V at 60 Hz frequency being modeled. This is then coupled together using inductors with the secondary circuit which is the sensor circuit. The turns ratio was selected by a regarded source on how to model noise source that gave a range of 500-1000 turns to 1 for noise simulation [17]. The choice of the resistor values was from the datasheets of the gas sensors that shows the sensing resistor is from this range due to various gas concentrations [6-7]. The coupling coefficent was calculated by using a derivation of the mutual inductance of two parallel wires while using the specifications of 14 AWG that is commonly used for wiring residential houses wall sockets as seen below [18-19]. 

distance between wires (d), radius of the wire (rw), and length of the wire of how long they run together (l). These calculations are taken from inches to meters in order to match the units, 1 inch = 0.0254 meters

```math
d= 3×0.0254 = 0.0762 m
```

```math
rw= 0.03205×0.0254 = 0.000814 m
```

```math
l= 6×0.0254 = 0.1524 m
```

```math
k = \frac{2 \times 4\pi \times 10^{-7} \times 0.1524}{3.14} \ln\left(\frac{0.0762}{0.000814}\right)^{-1} \text{ H/m}
```

```math
k = 1.3024 \times 10^{-9} \text{ H/m}
```



Figure 5. This is the ouputs of the simulation with the green sinusoid being the 2k ohm resistor and the 20k ohm resistor being the blue, hypothetically the 2k ohm resistor would be the most noise as seeing the larger sinusoid produced. The nosie being about 40mV as seen in the figure.



Figure 6. This is the schematic where a RC filter is introduced, this is useful in order to filter out the high frequencies and only capture the signal preserve home pro needs for accurate measuring.

The secondary circuit is modeled using a sinusoidal voltage source with a DC offset of 3.3V which is the ADC voltage range of the microcontroller being used in order to take the data and make it useful for the customer to understand, then factoring in ripple voltage from the wall wart which is specified 120mVpp on the datasheet [20]. 


Figure 8. The output simulation taken from figure 6 LTspice schematic on the secondary side after the filter.

After the filtering, looking at the green sinusoid, a measurement of 110 uVpp is found which is reduced from the 40mV seen in figure 5. 

Voltage resolution = 3.3V/4096 = 0.0008 V/step or 0.8mV/step

volts per ppm = 3.3/9990 = 0.00033 V/ppm

So the change of 1 ppm results in a change of 0.33mV, the noise level of 110uV is indeed significantly smaller than the voltage change associated with a 1 ppm change in gas concentration (0.33 mV). This confirms that the noise level is negligible compared to the resolution of the sensor.

steps per ppm = 4096/9990 = 0.41 step/ppm

volts per step = volts per ppm/ steps per ppm = 0.00033/0.41 = 0.0008 V/step 

The RC filtering shows that the noise being reduced to 110 uV. This would be negligible due to the volts per step being 0.8mV or 800uV. Because it is less than 1 ppm it would not matter. 
## Bill of Materials
| DEVICE | Quantity | Price Per Unit | Total Price |
| --- | --- | --- | --- |
|  SRAQ-G014 | 1 | $7.19 | $7.19 |
|  SRAQ-G016 | 1 | $18.99 | $18.99 |
|  2700uF capacitor | 3 | $2.29 | $6.87 |
|  1 ohm resistor | 3 | $0.23 | $0.69 |
|  Soldered Breadboard | 3 | $3.99 | $11.97 |
|  |  |  | $45.71 |

## References

[1] I. Maloca, J. Macan, V. Varnai, and R. Turk, “[household gas poisonings],” Arhiv za higijenu rada i toksikologiju, https://pubmed.ncbi.nlm.nih.gov/17265686/ (accessed Nov. 1, 2023). 

[2] OSHA, “1910.1000 table Z-1 - Table Z-1 limits for Air Contaminants,” Occupational Safety and Health Administration, https://www.osha.gov/laws-regs/regulations/standardnumber/1910/1910.1000TABLEZ1 (accessed Oct. 3, 2023).

[3] F. Alert, “Where to place smoke alarms, CO detectors and fire extinguishers in your home,” Where to Place Smoke Alarms, CO Detectors &amp; Fire Extinguishers, https://www.firstalert.com/us/en/safetycorner/do-you-know-where-to-place-your-fire-safety-devices/ (accessed Nov. 1, 2023). 

[4] Lowes, Regulatory information for CO alarms - lowes holiday, https://pdf.lowes.com/productdocuments/b416e051-dfbb-48d5-9e75-0cc2b15ea775/43462394.pdf (accessed Nov. 1, 2023). 

[5] C. Allcock, “Where to place your fixed gas sensors,” DSA Suppliers, https://dsasuppliers.com/blog/where-to-place-your-fixed-gas-sensors/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,sensors%20relative%20to%20the%20target%20gases%20vapour%20density (accessed Nov. 1, 2023). 

[6] L. Com, L, https://www.l-com.com/flammable-gas-sensor-mq9%3B-co-flammable-gas-analog-ttl-output-sraq-g014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 (accessed Nov. 1, 2023). 

[7] L. Com, L, https://www.l-com.com/ammonia-nh3-sensormq135-sraq-g016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 (accessed Nov. 1, 2023). 

[8] T. K. Hareendran, “How to use MQ-135 Gas Sensor,” Codrey Electronics, https://www.codrey.com/electronic-circuits/how-to-use-mq-135-gas-sensor/ (accessed Nov. 1, 2023). 

[9] tlfong01, “MQ9 learning notes,” tlfong01.blog, https://tlfong01.blog/2019/11/03/mq9-learning-notes/ (accessed Nov. 1, 2023). 

[10] “Why carbon monoxide (CO) alarms don’t need to be installed near the floor,” Google Nest Help, https://support.google.com/googlenest/answer/9259392?hl=en (accessed Nov. 1, 2023). 

[11] “Where should a fixed gas detector sensor be mounted?,” RKI, https://www.rkiinstruments.com/blog/where-should-a-fixed-gas-detector-sensor-be-mounted/ (accessed Nov. 1, 2023). 

[12] Sensidyne, “(NH3) ammonia gas detection,” Sensidyne, https://www.sensidynegasdetection.com/support/application-support/ammonia-gas-detection.php (accessed Nov. 1, 2023). 

[13] Espressif Systems, “ESP32-H2 - Espressif Systems,” Adafruit, https://www.espressif.com/sites/default/files/documentation/esp32-h2_datasheet_en.pdf (accessed Oct. 24, 2023).

[14] I. S. U. Share, “Binary world,” Binary World, https://loadingtech.blogspot.com/2012/07/binary-world.html (accessed Nov. 28, 2023). 

[15] S. One, “Bit to measurement resolution converter,” SensorsONE, https://www.sensorsone.com/bit-to-measurement-resolution-converter/#parts (accessed Nov. 28, 2023). 

[16] B. Murphy, “How do you deal with Sensor Data Noise, outliers, and missing values?,” Sensor Data Cleaning: Noise, Outliers, and Missing Values, https://www.linkedin.com/advice/0/how-do-you-deal-sensor-data-noise-outliers-missing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,the%20data%20analysis%20and%20modeling. (accessed Jan. 30, 2024). 

[17] Wideband power amplifier illustration | keysight, https://www.keysight.com/us/en/assets/9921-02529/help-files/5306PPD-FAQ-42.pdf (accessed Jan. 30, 2024).

[18] G. Lee, Guy LeeGuy Lee 16311 gold badge11 silver badge1313 bronze badges, and analogsystemsrfanalogsystemsrf 34k22 gold badges1919 silver badges4646 bronze badges, “Calculating mutual inductance in parallel wires,” Electrical Engineering Stack Exchange, https://electronics.stackexchange.com/questions/304211/calculating-mutual-inductance-in-parallel-wires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,the%20center_to_center%20distance%2C%20to%20be%20greater%20than%202%2Aradius (accessed Jan. 30, 2024).  

[19] T. Thiele, “A guide to electrical wire sizes,” The Spruce, https://www.thespruce.com/electrical-wire-sizes-1152851 (accessed Jan. 30, 2024). 

[20] Chicago Electronic Distributors, “Raspberry pi 4 power supply in white,” Chicago Electronic Distributors, https://chicagodist.com/products/raspberry-pi-4-psu-us-white?src=raspberrypi (accessed Jan. 30, 2024).

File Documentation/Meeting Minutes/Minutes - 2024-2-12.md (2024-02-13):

Opening
The team meeting of Capstone I Team 4 was held at 1:00 PM on February 12, 2024 in Brown Hall in room 408.

Present
Nate Campbell, Team Member
Luke Carson, Team Member
Cole Cooper, Secretary
Dylan Robbins, Team Member
Jackson Woodard, Team Lead

Absent
All members present

Approval of Agenda
No new agenda was added for this meeting

Business From Previous Meeting
Jackson, Dylan, and Cole are working on finishing the first submission of the Power Module’s sign off. The initial submission has been reviewed and needs more research. 

Nate and Dylan were able to get the water module signed off with a successful simulation of interference on the analog system

New Business 
Cole will reach out to Dr. Bhattacharya over more specific information on batteries that can be used. 

Additions to the Agenda
Luke needs to add updates to the schematic to show where the filter that prevents significant interference will go. 

Agenda for Next Meeting
Start team discussion of minimal functionality of this project.

Adjournment 
Meeting was adjourned at 6:00 PM by Jackson Woodard. With planning of meeting again on February 19, 2024 at 1:00 PM.

Minutes Submitted by: Cole Cooper
Approved by: Jackson Woodard

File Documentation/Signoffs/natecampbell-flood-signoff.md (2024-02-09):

# Flood Module Signoff

## Subsystem Function
The function of the flood subsystem is to detect the presence and level of water acting as an indicator of water damage within a home.
watrer

#### Sensor Operation
 [1]

The figure above shows how the water sensor's conductivity improves as it gets submerged in more water, lowering the resistance. When the sensor is exposed to less water, its conductivity decreases, thus resulting in higher resistance [1]. This sensor produces an output voltage that corresponds to its resistance, allowing the sensor to be calibrated to formulate a water level equation.

## Constraints
| No. | Constraints | Origin |
| --- | --- | --- |
|  1  | Sensor shall be able to detect if at least one inch of water is present in a room. | Project Team & Broader Implications |
|  2  | Sensors shall be able to detect water levels at various depths.| Project Team |
|  3  | Sensor shall send data to headunit in seconds if water is detected.| Project Team |
|  4  | Sensor shall be placed in areas flooding is most likely to occur. | Project Team |
|  5  | Sensor shall not be placed in areas where condensation can't easily form. | Broader Implications |

<sup>1</sup> 1-inch of water can cause thousands of dollars of damage [2]. Being able to detect a minimum of this depth would be essential in determining if a home has significant water damage. 

<sup>2</sup> Flood zones next to rivers and streams can average upwards of 3 feet in depth [3]. Being able to detect more than one inch of water could be valuable in determining how much water damage was done in a house.

<sup>3</sup> Knowing if water has touched the sensor could be a good indicator that a flood or leak has occurred. Being able to quickly send this data would be valuable in preventing a flood or leak from becoming catastrophic.

<sup>4</sup> Placing the sensors in the majority of the rooms and near the home's entrance will provide more accurate detection that water is present.

<sup>5</sup> Sensors placed in high condensation areas could lead to false positives, so preventing this is necessary.

## Buildable Schematic
#### Sensor Dimensions from Manufacturer

[4]

The figure shown above is the dimensions of 4965 water sensor.

#### Third-Party Buildable Schematic



The datasheet for the water sensor claims that it outputs an analog signal [4]. When fully submerged the analog value will be 3.3 volts because that is what is supplied by the esp-32.  Because of this it will need to be connected to the appropiate pin to process this data. According to the manufacturer, the GPIO1 pin on the ESP32 has a 12 bit analog to digital converter [5]. This will convert the output voltage from the sensor into a digital value of 0 to 4095 due to the 12 bits output from the converter. The sensor itself has 42 mm of sensing element that when divided by 4096 values equals about 10 micrometers per step. 

## Analysis
<sup>1</sup> The sensor itself has 42 mm or about 1.65 inches of measurable length. It could be placed at the bottom of a wall and measure a 1 inch depth easily.

<sup>2</sup> To measure depths beyond 1.65 inches, sensors can be placed at different heights on a wall. Knowing what height the sensor is at a coefficient can be derived to plug into the depth equation after calibrating the sensor.

<sup>3</sup> The sensor will be connected to the communication module powered by an ESP32 microcontroller. As stated in the communication sign-off, the microcontroller has a transmission rate of 250 Kbps and sends two packets of data at a time. The sensor will will output a max value of 4095 or 12 bits when converted. Even with the PAN ID and data type as mentioned in the communication module, one sensor reading will not take up the full 128 bits in the two-packet transmission. Since the ESP32 can send at a 250 Kbps rate, one reading will take less than a second to reach the head unit.

<sup>4</sup> Floodwater can enter a house through doors, windows, cracks in the foundation, sewer systems, and flood vents [6]. Placing the sensors near these areas could provide a more accurate response that flood damage has occurred. Placing multiple sensors at various heights in these locations can also provide the depth of water in the house. Assuming the home is level, the water from a flood will pool throughout the house, so placing a sensor at the base of every room will provide a more detailed view of where the water is in the house.

<sup>5</sup> Sensors that are placed in areas such as a bathroom where condensation is likely to occur will have to be placed with extra consideration to avoid false positives. Placing the sensors right outside the door of a bathroom or in a floor vent could prevent this condensation from building up while still allowing the system to detect if a flood has occurred in that room.

## Noise


The figure above shows a simulation of the sensor. It features noise from the wall mutually inducted with the sensor to simulate a wall wire running alongside the sensor along with noise from the power supply of the sensor.

The mutual inductance was found by using the formula and specifications below[7]:
```math
d= 3×0.0254 = 0.0762 m
```

```math
rw= 0.03205×0.0254 = 0.000814 m
```

```math
l= 6×0.0254 = 0.1524 m
```

```math
k = \frac{2 \times 4\pi \times 10^{-7} \times 0.1524}{3.14} \ln\left(\frac{0.0762}{0.000814}\right)^{-1} \text{ H/m}
```

```math
k = 1.3024 \times 10^{-9} \text{ H/m}
```
The winding values for the indcutors were chosen based on a help file from Keysight illustrating how to impose noise[8].

The ripple for the power supply was found in the datasheet for the power supply[9].

The 250 ohm resistor was chosen as that is what was measured from a similiar water sensor with resistance values from 250-750. The 250 ohm reading provides the simulation with more noise giving the worst case scenario. 



The image above shows the noise before the filter being close to 200 mV.





After filtering the noise is reduced to approximately 0.0008 volts. The RC values were chosen based on the filtering values for 60 Hz [10].

As for the resolution, testing the sensor yielded the output voltage to be .45 volts with miniscule submergence in water and .85 volts when fully submerged. This gives .4 volts of range. Because the ESP-32 operates on a 3.3 volts, the resolution will need to scaled down to use the .4 volt range. this can be found by 

3.3/4096= 0.00081 volts per step in normal 3.3 volt range

.4/.00081 ≈ 494 steps in the .4 volt range

.4/42 = 0.0095 volts per mm

494/42 = 11.76 steps per mm, due to the sensor having 42 mm of sensing element

.0095/11.76 ≈ 0.0008 volts per step

The effective noise reduction achieved by the filter will allow for better sensor accuracy, bringing the noise down to approximately 0.0008 volts, which is roughly equivalent to the 0.0008 volts per step. This single step of noise corresponds to an inaccuracy of about 0.085 mm (or 0.003 inches). Because floods are usually several inches and multiple sensors would be placed in the home at various heights, 0.003 inches is negligible to the accuracy of the sensor.

## Bill of Materials (BOM)
| DEVICE | Quantity | Price Per Unit | Total Price | Overall Total |
| --- | --- | --- | --- | ----- |
| 4965 Water Sensor | 1 | $1.95 | $1.95 | $1.95 |

## References
[1] Last Minute Engineers, “In-depth: How water level sensor works and interface it with Arduino,” Last Minute Engineers, https://lastminuteengineers.com/water-level-sensor-arduino-tutorial/ (accessed Nov. 1, 2023). 

[2] “The cost of flooding,” | Flood Damage Cost Calculator, https://www.floodsmart.gov/cost-flooding#:~:text=Just%201%20inch%20of%20water,a%20flood%20could%20cost%20you.&amp;text=Estimates%20based%20on%20national%20FEMA%20flood%20loss%20tables%20of%20cash%20value%20loss. (accessed Nov. 1, 2023). 

[3] “Zone ao,” FEMA.gov, https://www.fema.gov/glossary/zona-ao#:~:text=River%20or%20stream%20flood%20hazard,from%201%20to%203%20feet. (accessed Nov. 1, 2023). 

[4] 123 model (1) - adafruit industries, https://cdn-shop.adafruit.com/product-files/4965/Datasheet.pdf (accessed Nov. 1, 2023). 

[5] “Esp32-H2-DevKitM-1,” esp, https://docs.espressif.com/projects/espressif-esp-dev-kits/en/latest/esp32h2/esp32-h2-devkitm-1/user_guide.html (accessed Nov. 9, 2023). 

[6] “What are the effects of a flood on your home?,” PuroClean, https://www.puroclean.com/blog/effects-of-a-flood-home/ (accessed Nov. 2, 2023). 

[7] “Parallel wire inductance calculator - engineering calculators & tools,” All About Circuits, https://www.allaboutcircuits.com/tools/parallel-wire-inductance-calculator/ (accessed Feb. 6, 2024). 

[8] “How can noise be superimposed on the output of a DC power supply?,” How can noise be superimposed on the output of a dc power supply? - Technical Support Knowledge Center Open, https://edadocs.software.keysight.com/kkbopen/how-can-noise-be-superimposed-on-the-output-of-a-dc-power-supply-589744645.html (accessed Feb. 6, 2024).

[9] Raspberry pi 15W USB-C power supply, https://datasheets.raspberrypi.com/power-supply/15w-usb-c-power-supply-product-brief.pdf (accessed Feb. 6, 2024).

[10] “Low pass/high pass filter calculator,” RC, RL, LC Passive Filter Calculator | DigiKey Electronics, https://www.digikey.com/en/resources/conversion-calculators/conversion-calculator-low-pass-and-high-pass-filter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 (accessed Feb. 6, 2024).

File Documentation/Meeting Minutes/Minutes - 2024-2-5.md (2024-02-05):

Opening
The team meeting of Capstone I Team 4 was held at 1:00 PM on February 5, 2024 in Brown Hall in room 408.

Present
Nate Campbell, Team Member
Luke Carson, Team Member
Cole Cooper, Secretary
Dylan Robbins, Team Member
Jackson Woodard, Team Lead

Absent
All members present

Approval of Agenda
No new agenda was added for this meeting

Business From Previous Meeting
Finish remaining sign-offs.

New Business 
Jackson, Dylan, and Cole are working on finishing the first submission of the Power Module’s sign off.

Additions to the Agenda
Nate and Luke are finalizing power interference simulations in order to complete the Water and Gas Modules’ signoffs. 

Agenda for Next Meeting
Finish remaining sign-offs and get the prototype ready.

Adjournment 
Meeting was adjourned at 6:00 PM by Jackson Woodard. With planning of meeting again on February 12, 2024 at 1:00 PM.

Minutes Submitted by: Cole Cooper
Approved by: Jackson Woodard

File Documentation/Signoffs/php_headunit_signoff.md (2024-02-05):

# Head Unit Signoff

## Subsystem Function
The function of the head unit is to display active and historical data about each sensor that is used in the entire system. The head unit will be able to determine the differences between each sensor and catergorize the sensors together based on what room they are placed in. It will also be able to detect if the data from the sensor has reached the specified limit for each sensor and display a warning and start a timer if necessary. 

## Subsystem Constraints
| No. | Constraints | Origin |
| --- | --- | --- |
|  1  | The head unit shall know what sensor is sending data to it, the sensors location, and be able to differentiate from other sensors. | Team Supervisor & Project Team |
|  2  | The head unit shall be able to display and log active and historical data from sensors. | Project Team & Team Supervisor |
|  3  | The head unit shall be able to detect if the fire module temperature is at 176&#176; Fahrenheit or higher and display a warning. | Project Team |
|  4  | The head unit shall be able to receive data from the water module to display a warning if water is present and the total water depth. | Project Team |
|  5  | The head unit shall be able to receive data and follow OSHA standards for ammonia, propane, and carbon oxides (50 ppm, 1000 ppm, and 50 ppm respectively over an eight hour window). | Standards & Project Team |
|  6  | The head unit shall be able to interpret, from the received data, that mold could form if the humidity levels exceed 50% and temperatures range between 55&#176; and 85&#176; Fahrenheit for a minimum of two days. | Project Team |

<sup>1</sup> The head unit needs to know what sensor is sending data to it, the sensors location, and be able to differentiate from other sensors. This allows us to identify which sensor is detecting an issue to let the homeowner know where an issue has occurred and what type of issue has occurred. 

<sup>2</sup> The head unit is responsible for displaying all logged data from the sensor modules. The historical data is important for showing that the house has not had any issues like mold buildup, fire, water buildup, or gas leaks. If an issue has occured then the system should be able to show how long there is a type of issue. This information is can be used to prove the value of a house.

<sup>3</sup> The head unit checks if temperatures have been at 176&#176; Fahrenheit or higher, since 176&#176; Farhenheit is the ignition temperature of drywall [1]. 

<sup>4</sup> The head unit checks if water is detecte and what the level of water is acting as an indicator of water damage within a home. Water can cause damages like mold growth, vermine infestations, and even weakend foundations [2].

<sup>5</sup> The head unit needs to know if ammonia, propane, and carbon oxides are present. These gases can cause the poisoning of inhabitants or cause fires when present [3]. 

<sup>6</sup> The head unit is required to know if mold is accumulating by checking if the humidity levels exceed 50% and temperatures range between 55&#176; and 85&#176; Fahrenheit for a minimum of two days. The build up of mold can cause health issues to occupants in the house like trouble breathing or full allegic reactions as well as weaken the foundations of the house [4]. 

## System Schematic

Head_Unit_Schematic_Design_V2

Headunit Enclosure

## Analysis

<sup>1</sup> The head unit will know which sensor is detecting an issue to let the homeowner know where an issue has occurred and what type of issue has occurred. This information will be determined by using each module's PAN ID. For the head unit to be able to communicate with each module, a XB24 will be used. The Raspberry Pi 4 will be able to communicate with the XB24 using the RX and TX UART communication pins. The Raspberry’s RX pin, pin 16, is the receive pin that the Raspberry Pi 4 will use for the reception of data from the XB-24’s UART Data Out, pin 2. While, the Raspberry’s TX 1 pin 15 is the transmit pin that the Raspberry Pi 4 will use for the transmission of data to the XB-24’s UART Data In, pin 3. 

<sup>2</sup> The head unit needs to be able to compute, store and display data received from the modules. Computing the data is comparing the received values compared to a database of acceptable versus unacceptable values.
The data base of values is defined by specifications mentioned in each sensor module section. The Raspberry Pi 4 B has at minimum 2 GBs of RAM, which allows us to keep 16,000,000,000 bits of data at any given moment while powered on. This allows the head unit to hold onto an active library of checked information from 100 modules received every second with over a 24 hour period leaves 14,000,000,000 bits for holding the values of comparison. Additional storage is required since the Raspberry Pi 4 does not come with ROM storage. 32 gigabytes of sd storage would give us ample storage for holding information from 100 modules recorded every second for over a year for 100 modules. For the 30 year targert a 1 terabyte USB hard drive or solid state drive would still have over 1,900,000,000,000 bits remaining. In the case of the team's four modules there will be 8,051,097600 bits would be stored in the 274,900,000,000 bit -32 gigabyte- SD card. Finally the data needs to be readable by the user, which can be solved easily by taking advantage of the RPI-Display Port output on the Raspberry Pi and its power out in order to power and use a touch screen display. Using a touch screen display allows the user to interact with the head unit and choose what information should be displayed. 

<sup>3</sup> According to the EPA, North America accounts for over 50% of the worldwide consumption of drywall [5].  176&#176; Farhenheit is the ignition point of drywall, which is used in North American household construction. The head unit will compute temperatures from the fire module and check if that temperature reaches over 176&#176; Farhenheit.

<sup>4</sup> The head unit will check if water has accumulated in parts of the home it is not supposed to be. The presence of water can cause mold, foundation damage, or show that a water line has busted [2].

<sup>5</sup> The head unit will check if common household gasses -Ammonia, Carbon-Oxides, and Propane- have accumulated past an acceptable threshhold. The gas thresholds are 50 ppm, 1000 ppm, and 50 ppm respectively over an eight hour window. According to OSHA this is the minimum amount of time the gasses can be present before major health issues [3].

<sup>6</sup> The head unit will check if temperature is in the range between 55&#176; and 85&#176; Fahrenheit and if humidity levels exceed 50% over a period of two days. This is the minimum amount of time that it takes for mold to grow in a house [4].

## Bill of Materials (BOM)

| DEVICE | Quantity | Price Per Unit | Total Price | Overall Total |
| --- | --- | --- | --- | ----- |
| Raspberry Pi 4B | 1 | $45.00 | $45.00 | |
| 7" 800x480 TFT DSI Capacitive Touchscreen | 1 | $54.90 | $54.90 | |
| 32 GB Micro SDHC Memory Card | 1 | $9.51 | $9.51|  |
| PLA Filament 1.75 mm 1 KG | 1 | $13.99 | $13.99 | $123.40 |

## References
[1] N. P. Team, “At what temperature will drywall ignite?,” NCERT POINT, https://www.ncertpoint.com/2022/01/at-what-temperature-will-drywall-ignite.html (accessed Oct. 24, 2023).

[2] Stueber, S. (2023, October 4). What are the common causes of water damage?. West Bend Insurance of Wisconsin. https://www.thesilverlining.com/westbendcares/blog/what-are-the-common-causes-of-water-damage (accessed Oct. 31, 2023).

[3] I. Maloca, J. Macan, V. Varnai, and R. Turk, “[household gas poisonings],” Arhiv za higijenu rada i toksikologiju, https://pubmed.ncbi.nlm.nih.gov/17265686/ (accessed Nov. 1, 2023).

[4] MediLexicon International. (n.d.). Mold in the home: How big A health problem is it?. Medical News Today. https://www.medicalnewstoday.com/articles/288651#mold-and-health (accessed Oct. 28, 2023).

[5] Huang, X. AND T. Tolaymat. Characterization of Drywall Products for Assessing Impacts Associated with End-of-Life Management. U.S. Environmental Protection Agency, Washington, DC, EPA/600/R-20/286, 2020.

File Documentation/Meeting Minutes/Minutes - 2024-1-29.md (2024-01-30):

Opening
The team meeting of Capstone I Team 4 was held at 1:00 PM on January 29, 2024 in Brown Hall in room 408.

Present
Nate Campbell, Team Member
Luke Carson, Team Member
Cole Cooper, Secretary
Dylan Robbins, Team Member
Jackson Woodard, Team Lead

Absent
All members present

Approval of Agenda
No new agenda was added for this meeting

Business From Previous Meeting
Finish remaining sign-offs.

New Business 
Nate is responsible for finishing the water detection module. In order for this module to be completed, designing a circuit to minimize possible ripple voltage on the analog sensor. 

Luke is responsible for finishing the gas detection module. In order for this module to be completed, designing a circuit to minimize possible ripple voltage on the analog sensor. 

Cole is responsible for finishing the head unit module. In order for this module to be completed the proof of what microcontroller is needed with evidence supporting the claims.

Additions to the Agenda
Jackson is responsible for figuring out the coding for enabling the ESP-32 H2’s to read sensor data and communicate with the head unit.

Dylan is responsible for starting the power module in order to show a solid start in the good faith effort.

Agenda for Next Meeting
Finish remaining sign-offs and get prototype ready.

Adjournment 
Meeting was adjourned at 2:30 PM by Jackson Woodard. With planning of meeting again on February 5, 2024 at 1:00 PM.

Minutes Submitted by: Cole Cooper
Approved by: Jackson Woodard

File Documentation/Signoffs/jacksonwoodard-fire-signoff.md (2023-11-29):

# Fire Module Signoff

## Subsystem Function
The function of the fire module subsystem is to detect if a fire has ever occurred in a specific room in a house. The system will work by using an IR Temperature Sensor that is installed on the ceiling of a room that will be pointed toward the ground to detect room temperature to determine if a minimum of 176&deg; Fahrenheit has occurred. If the temperature has reached a critical temperature level, a signal will be sent from the transmitter (ESP32-H2) to the head unit warning the homeowner of a potential fire.

firemodule

## Constraints
| No. | Constraints | Origin |
| --- | --- | --- |
|  1  | Shall be able to detect the minimum temperature of 176&deg; Fahrenheit. | Project Team |
|  2  | Shall send sensor data to the ESP32 every second. | Project Team |
|  3  | Shall send temperature data to the head unit if 176&deg; Fahrenheit has been reached. | Project Team |
|  4  | Shall not be a distraction to the homeowner. | All External Stakeholders, Ethics, & Team Supervisor |

<sup>1</sup> To determine if a fire has occurred in a room, the temperature sensor needs to be able to detect if the temperature has reached a minimum of 176&deg; Fahrenheit. This is because drywall in a house begins to deteriorate at 176&deg; Fahrenheit [1]. 

<sup>2</sup> To monitor the temperature of a room, the ESP32 will need to read the data of the sensor every second. If the temperature is recorded every second, the system will be able to detect if a fire has formed and warn the homeowner.

<sup>3</sup> If the ESP32 reads in the data from the temperature sensor and the temperature is 176&deg; Fahrenheit or higher, the ESP32 needs to send the data to the head unit so the head unit can warn the homeowner.

<sup>4</sup> One of the objectives of this system is for it to not be a distraction to the homeowner. According to homeowners, they do not want a system that is a distraction to their everyday lives.

## Buildable Schematic

BlockDiagram

The picture shown above is the detailed block diagram of the MLX90614 IR Temperature Sensor. The MLX90614 is controlled by an internal state machine that controls the measurements and calculations of the object and ambient temperatures and does the post-processing to output the data [2].

#### Third-Party Buildable Schematic

FireModule

According to the datasheet, the temperature sensor uses an I2C communication protocol for the data output pins (SDA/PWM & SCL/Vz) [2]. The ESP32-H2 can interpret data that uses the I2C communication protocol, and every GPIO pin on the ESP32-H2 supports the I2C communication protocol [3]. The I2C pins can be chosen by configuring, in coding, which GPIO pins are going to be used for I2C communication [3]. The SDA/PWM pin is used to read and send data, and the SCL/Vz pin is used for the clock signal [2].

FireModuleEnclosure_XRay
FireModuleEnclosure_Realistic

The pictures shown above are the 3D Models of the enclosure that is going to be used for this module. The smaller box is used to hold the sensor with the sensor facing down out of the hole to detect temperature. The larger box is used to hold the ESP32-H2. The two divots are used for wire management and for the ESP32-H2 to receive power from the power module. Both boxes are made to fit their respective parts snugly with only a little room for connection purposes. The lid will be screwed on with two screws and will be able to be taken off to access the components. The four holes on the outside are used to screw the enclosure into the ceiling.

## Analysis

<sup>1</sup> Drywall starts getting damaged at 176&deg; Fahrenheit [1]. The MLX90614ESF-BAA infrared temperature sensor measures from -70&deg;F to 716&deg;F, so it can detect this temperature [2]. When measuring temperature, a resolution of whole numbers (176&deg;F / 300&deg;F) will work efficiently because temperature in decimals would not be necessary for determining if a fire has potentially formed. This can be coded in the microcontroller to only output desired values.

<sup>2</sup> The ESP32-H2 is a microcontroller that can be coded to read how often it pulls data from the connected sensor [3]. Having enough storage to hold the data would not be a problem for the ESP32, as proved in the communication module. 

The MLX90614 has an ADC that converts analog data to digital data before transmission to the microcontroller [2]. The SDA/PWM and SCL/Vz pins connect to a 12-bit I2C-compatible pin on the ESP32-H2 for communication. The temperature sensor's output pins will transmit less than 12 bits of information [2][3].

<sup>3</sup> The ESP32-H2 can be coded to send the data to the head unit if 176&deg; Fahrenheit is read from the sensor [4]. The fire module is designed to transmit data to the ESP32 every second, as stated above, and once the temperature value of 176&deg; Fahrenheit or higher is received, the ESP32 will send the data to the head unit.

<sup>4</sup> The fire module is going to be designed in a way that will not be too noticeable to a homeowner. The entire module will be put inside an enclosure that will be mounted on the top side of a ceiling panel so it will not be noticeable. The sensor will be placed at the bottom of the enclosure with a hole in the ceiling panel allowing the sensor to measure the temperature of a room.

## Bill of Materials (BOM)
| DEVICE | Quantity | Price Per Unit | Total Price |
| --- | --- | --- | --- |
|  HiLetgo GY-906 MLX90614ESF | 1 | $15.99 | $15.99 |

## References

[1] N. P. Team, “At what temperature will drywall ignite?,” NCERT POINT, https://www.ncertpoint.com/2022/01/at-what-temperature-will-drywall-ignite.html (accessed Oct. 24, 2023).

[2] DigiKey, “MLX90614ESF-BAA-000-SP Melexis Technologies NV - DigiKey,” Melexis Technologies NV MLX90614ESF-BAA-000-SP, https://www.digikey.com/en/products/detail/melexis-technologies-nv/MLX90614ESF-BAA-000-SP/5414793 (accessed Oct. 24, 2023). 

[3] Espressif Systems, “ESP32-H2 - Espressif Systems,” Adafruit, https://www.espressif.com/sites/default/files/documentation/esp32-h2_datasheet_en.pdf (accessed Oct. 24, 2023).

[4] Hiletgo GY-906 MLX90614ESF non-contact infrared temperature sensor ..., https://www.amazon.com/HiLetgo-MLX90614ESF-Non-contact-Infrared-Temperature/dp/B071VF2RWM (accessed Oct. 31, 2023).

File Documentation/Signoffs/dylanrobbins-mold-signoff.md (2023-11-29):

# Mold Module Signoff

## Subsystem Function
The function of the mold module subsystem is to detect if mold is likely to grow within the surrounding environment of the sensor. The SHT30 Temperature and Humidity Sensor will gather temperature and humdity levels and send its respective data to an ESP32-H2 micro-controller. The mold module will send data to the ESP32-H2 every hour to allow for computations of the peak and average values.



## Constraints
| No. | Constraints | Origin |
| --- | --- | --- |
|  1  | Shall be able to detect temperature ranges between 55&deg; F - 85&deg; F and humidity levels exceeding 50% RH. | Project Team |
|  2  | Shall be able to communicate through I2C protocol and send data once every hour to its local ESP32-H2 transmitter, then enter sleep mode until the next hour. | Project Team |
|  3  | Shall be protected and not exposed to harsh environmental conditions to prevent any damage to the sensor. | All External Stakeholders, Ethics, & Team Supervisor |
|  4  | Shall give precise temperature and humidity readings within 0.5&deg; F and 2% RH of the actual values, rounding to the nearest whole number to properly evaluate and determine if mold like conditions are present. | Project Team |

<sup>1</sup> The humidity and temperature sensors must be able to detect the specified levels because mold like conditions are highly probable when in those ranges. The highest probability of mold occurs when the temperature is 80&deg; F and the relative humidity level is 95% [3]. Other mold like conditions arise when temperatures are between 55&deg; F - 85&deg; F and humidity levels exceeding 50% RH.

<sup>2</sup> The sensor must be able to communicate to the ESP32-H2 microcontroller through I2C protocol because they are both compatible with I2C. Also, sending the sensor readings every hour will allow for lower power consumption and preserved storage space because the microcontroller can be put in sleep mode while not receiving data, and mold like conditions take longer periods of time to form.

<sup>3</sup> The sensors are expected to have a long life-time because they will not be easily accessable for repair inside of a wall. To ensure that they will have a longer life-time, the sensor will be protected in a way that harsh environmental conditions will not cause damage.

<sup>4</sup> In order for the sensor module to accurately determine if mold like conditions are present, the sensor must record precise measurements. The percent error of the readings must be very low so that the data is as accurate as possible. A slight error in the readings could possibly cause the system to display no active mold conditions when there actually is.

## Buildable Schematic
SHT30 functional block diagram

The picture above is a functional block diagram of the SHT30-DIS humidity and temperature sensor. The SHT30 has relative humidity and temperature sensors on board that send their readings to an analog to digital converter. The data is then passed on to be processed and linearized and also interfaced to provide digital output in the form of I2C communication [1].

SHT30 typical application circuit

The picture above is the typical application circuit for the SHT30-DIS humidity and temperature sensor [1]. The buildable schematic of the SHT30 hooked up to the ESP32-H2 will be shown below. The only pins required to be hooked up to the ESP32-H2 are the VDD (power), VSS (ground), SDA (Serial data), and SCL (Serial clock) pins. The remaining pins will be floating, with the necessary pins being configured in the code of the ESP32-H2 to allow for appropriate communication.

Mold Module Schematic

The picture above is the third party buildable schematic for the mold module. The nRESET, ALERT, ADDR, and R pins can be left unconnected because the sensor will still be able to have full functionality. For this design, these pins are unnecessary for physical hook ups because they can each operate with their default settings through I2C communication. According to the datasheet, any GPIO pin can support I2C peripherals [2]. Therefore, SCL and SDA can be connected to the GPIO 1 and GPIO 2 pins and coded to be supported by the I2C protocol.

## Analysis
<sup>1</sup> According to the SHT30-DIS datasheet, the sensor can detect relative humidity levels from 0% - 100% RH and can detect temperature values between -40&deg; C - 125&deg; C [1]. Given these ranges, the SHT30-DIS will have no problem detecting the ranges of values that are probable to cause mold like conditions.

<sup>2</sup> The SHT30-DIS requires an I2C, 2 wire connection, communication protocol to communicate with any micro-controller [1]. The ESP32-H2 has many advanced peripherals, but it most importantly has two I2C bus interfaces that can be accessed on any GPIO pin [4]. Therefore, the ESP32-H2 can support I2C communication protocols and communicate with the SHT30 if the SDA (Serial data) and SCL (Serial Clock) pins are properly connected to the ESP32-H2. Since the SHT30 and ESP32-H2 are compatible with each other, the sensor can send its data to the microcontroller for computation and storage. The SHT30 is reliably capable of sending data across the SDA line at 400 kHz, but the I2C fast mode standards must be met. In I2C communication, one bit is transmitted each clock cycle and there are 400,000 clock cycles per second, so the SHT30 can transmit 400,000 bps to the ESP32-H2. Therefore, if 32 bits of data are being transmitted to the ESP32-H2 every hour, 16 bits for the temperature value and 16 bits for the humidity level, the SHT30 can transmit this data in 0.08 ms, and the ESP32-H2 can go into sleep mode until it is woken up in another hour. This will help with lower power consumption and preserve storage space.

Transmission Time = Number of Bits / Transmission Rate

Transmission Time = (32 bits) / (400,000 bps)

Transmission Time = 0.08 ms

<sup>3</sup> According to all external stakeholders and team supervisor, the system shall not be of visual hindrance to the home owner and require little to no maintenance during its lifespan. The design team is proposing to design the system to last up to 30 years. Therefore, the sensor shall not be exposed to any harsh environmental conditions that might damage it. The SHT30-DIS is designed and produced inside of an enclosed case much like weather-proof mesh sensor [2]. This will ensure that nothing, such as rodents or debris, will damage the sensor while still maintaining a stable, accurate reading of temperature and humidity levels. All of the external connections to the ESP32-H2 will also be within an enclosed case.

<sup>4</sup> To ensure that the mold module is reading and computing accurate numbers to determine if mold like conditions are met, the SHT30 must have low accuracy tolerances. According to the datasheet, the humidity sensor has a typical tolerance of +/- 2% RH and the temperature sensor has a typical tolerance of +/- 0.2&deg; C when levels are between 0&deg; C to 65&deg; C [1]. This sensor is more precise, more accurate, works in a bigger range of temperature/humidity, and is less expensive compared to other humdity and temperature senors, such as the DHT22/AM2302 [4]. With more accurate readings, the ESP32-H2 will be able to compute more accurate peak and average values to better trace mold conditions.

## Bill of Materials (BOM)
| Device | Quantity | Price Per Unit | Total Price |
| --- | --- | --- | --- |
| SHT30 Temperature and Humidity Sensor | 1 | $13.41 | $13.41 |

## References
[1] Sensirion, “NRESET - Adafruit Industries,” Datasheet SHT3x-DIS Humidity and Temperature Sensor, https://cdn-shop.adafruit.com/product-files/5064/5064_Sensirion_Humidity_Sensors_SHT3x_Datasheet_digital.pdf (accessed Oct. 31, 2023).

[2] A. Industries, “SHT30 temperature and humidity sensor - wired enclosed shell,” adafruit industries blog RSS, https://www.adafruit.com/product/5064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 (accessed Oct. 31, 2023).

[3] Adam, “Mold Chart for Temperature and Humidity Monitors,” Stetten home services, https://energyhandyman.com/knowledge-library/mold-chart-for-temperature-and-humidity-monitors/ (accessed Sep. 28, 2023).

[4] Espressif Systems, “ESP32-H2 - Espressif Systems,” Adafruit, https://www.espressif.com/sites/default/files/documentation/esp32-h2_datasheet_en.pdf (accessed Oct. 24, 2023).

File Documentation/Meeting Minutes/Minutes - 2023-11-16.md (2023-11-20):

Opening
The team meeting of Capstone I Team 4 was held at 12:00 PM on November 16, 2023 in Brown Hall in room 408.

Present
Nate Campbell, Team Member
Luke Carson, Team Member
Cole Cooper, Secretary
Dylan Robbins, Team Member
Jackson Woodard, Team Lead
Jesse Roberts, Sponsor

Absent
All present

Approval of Agenda
The agenda was unanimously approved by the team.

Approval of Minutes
The meeting minutes were unanimously approved by the team.

Business From Previous Meeting
The completion of our first design submission’s first full sign off.

New Business 
No new business was started from this meeting. 

Additions to the Agenda
This meeting started with more clarifications on how to properly explain that the data transfer needed can be done for proper communication between each sensor and its ESP 32. We then went through a deep dive on necessities for how the head-unit should function for the system. We have come to the conclusion that the Raspberry Pi 3a/4 will be perfect for our needs. The reason we went a different route was the expectation that the head-unit needs to stay on while the power is out, we have determined now that the head-unit does not need power during a power outage thus negating the original concerns. Mention that the team needs more specific information for fully explaining details was brought up, like the communication protocols that the sensors use like I2C. We also found that the ESP-32 H2’s analog to digital converters handle 0-3.3 V steps with a resolution of 4096 points of values. 

Agenda for Next Meeting
Finish remaining sign-offs.

Adjournment 
Meeting was adjourned at 3:00 PM by Jackson Woodard. With planning of meeting again on November 21, 2023 at 12:00 PM.

Minutes Submitted by: Cole Cooper
Approved by: Jackson Woodard

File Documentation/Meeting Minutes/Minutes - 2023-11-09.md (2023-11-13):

Opening
The team meeting of Capstone I Team 4 was held at 12:00 PM on November 9, 2023 in Brown Hall in room 408.

Present
Nate Campbell, Team Member
Luke Carson, Team Member
Cole Cooper, Secretary
Dylan Robbins, Team Member
Jackson Woodard, Team Lead
Jesse Roberts, Sponsor

Absent
All present

Approval of Agenda
The agenda was unanimously approved by the team.

Approval of Minutes
The meeting minutes were unanimously approved by the team.

Business From Previous Meeting
The completion of our first design submission’s first full sign off.

New Business 
No new business was started from this meeting. 

Additions to the Agenda
This meeting started out by asking about direct feedback by each group member on their ongoing sign-offs. Mr. Roberts added in this feedback that we need to include an explanation that pins from the ESP 32s to the individual sensors work with the data being sent between sensors and ESPs. Since the parts we are implementing are mostly existent already, we just need to use the data-sheets to prove such claims. Another piece of conversation included the team asking if our interpretation of the given feedback for the sign-offs has been correct. Mr. Roberts and the team have come to an agreement that the total number of ESP 32s will equal three instead of the five that were originally requested. Major modifications for the original power system are needed. We have been requested to fully develop an uninterruptible power supply, UPS, instead of using a pre-built option. 

Agenda for Next Meeting
Finish remaining sign-offs.

Adjournment 
Meeting was adjourned at 3:00 PM by Jackson Woodard. With planning of meeting again on November 9, 2023 at 12:00 PM.

Minutes Submitted by: Cole Cooper
Approved by: Jackson Woodard

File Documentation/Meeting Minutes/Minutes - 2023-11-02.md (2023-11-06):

Opening
The team meeting of Capstone I Team 4 was held at 12:00 PM on November 2, 2023 in Brown Hall in room 408.

Present
Nate Campbell, Team Member
Luke Carson, Team Member
Cole Cooper, Secretary
Dylan Robbins, Team Member
Jackson Woodard, Team Lead

Absent
Jesse Roberts, Sponsor

Approval of Agenda
The agenda was unanimously approved by the team.

Approval of Minutes
The meeting minutes were unanimously approved by the team.

Business From Previous Meeting
The completion of our first design submission’s first full sign off.

New Business 
No new business was started from this meeting. 

Additions to the Agenda
After reviewing more feedback from Mr. Roberts, more information and explanations were needed for the communications sign-off. 
The team all focused on responding to the feedback. The other individual submissions also received some feedback, 
so the team worked on addressing their individual feedback as well. More discussion of what microcontroller is needed for the head unit also occurred. 
We found that the Raspberry Pi 3 and 4 use too much power for us to realistically keep powered through a two-week power outage. 
We then talked about moving to an Arduino based head unit since Arduinos do have a sleep mode. 
The Arduino Uno Rev3 will not work since it does not have enough ports for interfacing with the XB-24, the 2.7” TFT display, and additional storage. 
The Arduino Mega 2560 Rev3 should be able to work with our requirements based on initial research.

Agenda for Next Meeting
Finish remaining sign-offs.

Adjournment 
Meeting was adjourned at 3:00 PM by Jackson Woodard. With planning of meeting again on November 9, 2023 at 12:00 PM.

Minutes Submitted by: Cole Cooper
Approved by: Jackson Woodard

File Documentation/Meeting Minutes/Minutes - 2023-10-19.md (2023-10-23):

Opening
The team meeting of Capstone I Team 4 was held at 12:00 PM on October 19, 2023 in Brown Hall in room 408.

Present
Nate Campbell, Team Member
Luke Carson, Team Member
Cole Cooper, Secretary
Dylan Robbins, Team Member
Jackson Woodard, Team Lead
Jesse Roberts, Sponsor

Absent
All Present

Approval of Agenda
The agenda was unanimously approved by the team.

Approval of Minutes
The meeting minutes were unanimously approved by the team.

Business From Previous Meeting
The completion and publishing of the conceptual design and block diagram.

New Business 
No new business was started from this meeting. 

Additions to the Agenda
The team is thinking about submitting the head unit’s design first. Questions of what data and how much will be sent and stored. We also need to know how often the data will be stored by the head unit. We will need to know specifics like how the power input can handle ripple voltage and current. The team has also recognized that there might be certain points where we have multiple good options to do the same job, leaving a more or less arbitrary decision. 

Agenda for Next Meeting
The completion of our first design submission.

Adjournment 
Meeting was adjourned at 3:00 PM by Jackson Woodard. With planning of meeting again on October 26, 2023 at 12:00 PM.

Minutes Submitted by: Cole Cooper
Approved by: Jackson Woodard

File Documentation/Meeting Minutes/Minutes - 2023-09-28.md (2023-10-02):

Opening
The team meeting of Capstone I Team 4 was held at 12:00 PM on September 28, 2023 in Brown Hall in room 408.

Present
Nate Campbell, Team Member
Luke Carson, Team Member
Cole Cooper, Secretary
Dylan Robbins, Team Member
Jackson Woodard, Team Lead
Jesse Roberts, Sponsor

Absent
All Present

Approval of Agenda
The agenda was unanimously approved by the team.

Approval of Minutes
The meeting minutes were unanimously approved by the team.

Business From Previous Meeting
Creation of the flow chart for conceptual design and initial rough draft for conceptual design.

New Business 
Finding specific information to better define what information is being recorded by the sensors, like mold growth conditions.

Additions to the Agenda
The first issue mentioned was defining how to switch between the wall power of 120V and battery power without a delay. The use of an uninterruptible power supply, UPS, could be a useful way to switch power sources for the event of power outages. A redefinition of the shall statements was mentioned, like “battery will last for 2 weeks.” A more detailed focus of the block diagram was requested, this can be done by specifying more information to fully determine the function of each aspect of our system. The idea of having dumb sensors was mentioned and could work well for our use case. In order for “dumb sensors” to work, they still need to transmit useful tag information like sensor name and number for this method to work. The inclusion of how our system can add value to homeowners has been appreciated by Mr. Roberts.

Agenda for Next Meeting
Edits of the flow chart for conceptual design and draft for conceptual design.

Adjournment 
Meeting was adjourned at 4:00 PM by Jackson Woodard. With planning of meeting again on October 5, 2023 at 12:00 PM.

Minutes Submitted by: Cole Cooper
Approved by: Jackson Woodard

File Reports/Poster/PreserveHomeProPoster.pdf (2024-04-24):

# Abstract

# Preserve Home Pro (House Health Monitoring)

Luke Carson, Cole Cooper, Jackson Woodard, Dylan Robbins, Nate Campbell

# Specifications

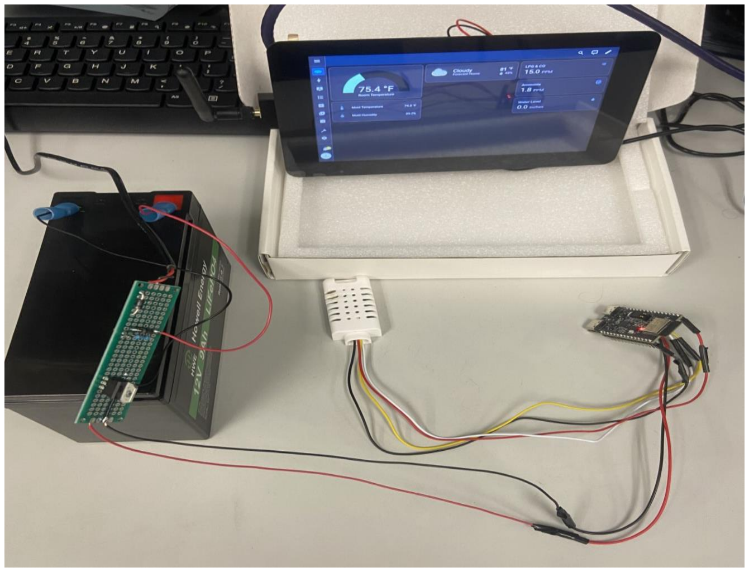
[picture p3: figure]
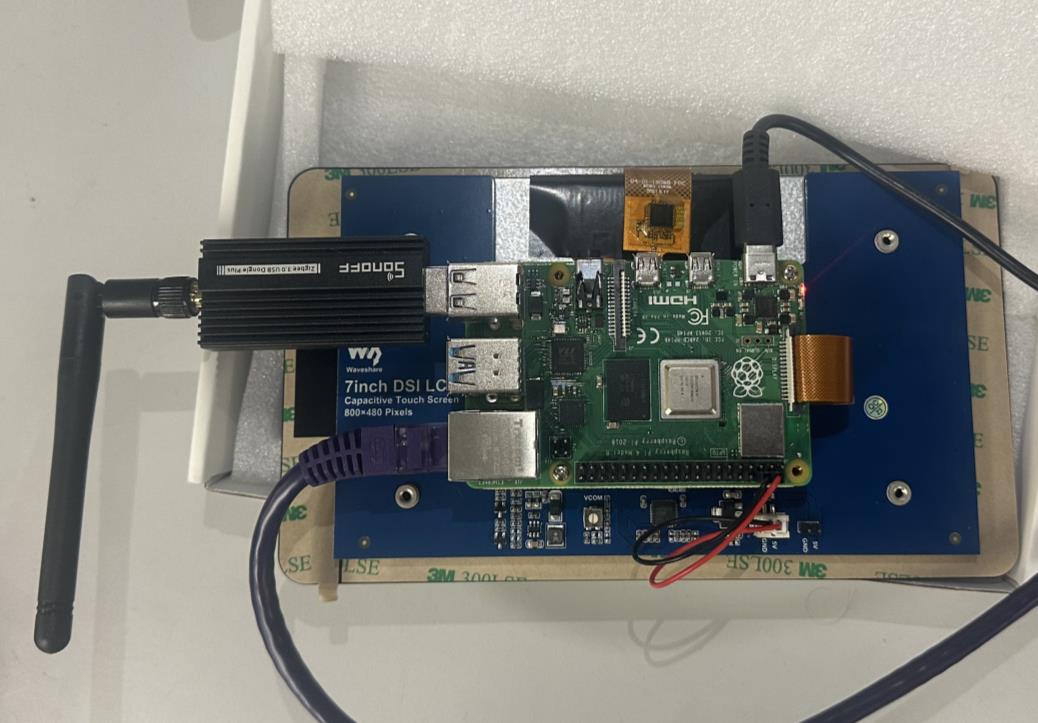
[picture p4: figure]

# Acknowledgements

# Design

# Experimentation & Results

# Budget

# Future Work

The Preserve Home Pro is a proposed system that monitors house health. It proposes a collection of sensors and a head unit to measure, record, and display important data. The system aims to provide homeowners with valuable information to help maintain and protect the value of their homes. It will be designed as a semi-permanent system that will last up to thirty years and will communicate information through a closed network without requiring the Internet.

- Head Unit: provides historical and current data for each sensor.
- Communication: wirelessly transmits data via Zigbee protocol.
- Power: uses mains of the house then switches to a UPS during outages.
- Sensors: four sensor modules to detect problems in the house.

The team would like to give thanks to Jesse Roberts for his support throughout the entire Capstone Project. Finally, the team would like to thank one of the external stakeholders, Wes Harris from State Farm, for providing insights to advance the project. Lastly, to Dr. Bhattacharya for his help on the power module.

- User Interface: Home assistant acts as a controller hub that allows different sensor entities to be integrated in one service.
- ESP32-H2: microcontrollers that allow wireless
data communication through Zigbee protocol.
- Raspberry PI 4B: microcontroller used for head unit system that receives, displays and logs sensor data.
- Power: primarily uses the house's main service but with an outage a UPS will be switched on for a secondary service.

### - Sensors:

- Gas- detects propane, carbon monoxide, ammonia.
- Water- detects the depth of water if present.
- Fire- detects if a fire has started in the house.
- Mold- detects conditions of the house that mold grows in.
- Implementation into an actual household would be the ultimate goal of this project.
- Better accuracy for more reliable data measurements and history documentation.
- More sensors for other applications.
Module | Cost
Head Unit Module | $123.40
Communication Module | $100.30
Power Module | $96.24
Flood Module | $9.99
Fire Module | $15.99
Mold Module | $13.41
Gas Module | $45.71
Total Cost | $405.04

Figure 4: Humidity Test Results

Figure 5: UI with Active Sensor Readings

GitHub
Repository
→

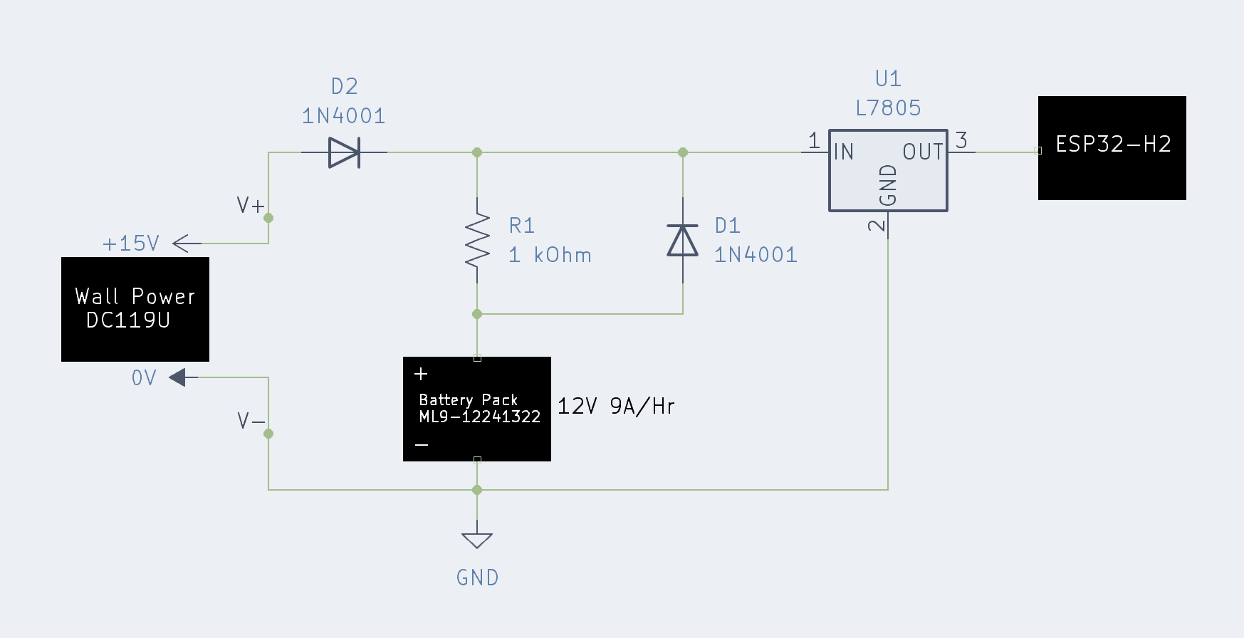
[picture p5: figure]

Figure 3: UPS Schematic

Figure 1: UPS with Attached Sensor | Figure 2: Raspberry Pi & Zigbee Dongle

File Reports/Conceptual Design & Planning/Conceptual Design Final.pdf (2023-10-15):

# Conceptual Design

Jackson Woodard, Dylan Robbins, Nathaniel Campbell, Luke Carson, Cole Cooper
Electrical and Computer Engineering Department Tennessee Technological University Cookeville, Tennessee
jrwoodard44@tntech.edu, dcrobbins42@tntech.edu, nmcampbell43@tntech.edu, lmcarson43@tntech.edu, cacopper44@tntech.edu
I. INTRODUCTION

Houses face many types of issues like gas leaks, fires, floods, and mold, which cause damage to the house leading to a decrease in value [1]–[3]. Unlike a smartphone or a modern car, current house constructions lack a mechanism to detect and monitor this information. This information, such as knowing if water damage has occurred, could improve the value of the house by proving that issues have not occurred or were taken care of quickly by the homeowner. To detect and monitor all of these problems, this project proposes a collection of sensors and a head unit, called Preserve Home Pro. The goal of the system is to measure, record, and display important active and historical data, giving a homeowner valuable information to help maintain and protect the value of their home. The Preserve Home Pro will be designed as a semi-permanent system that will last for up to thirty years. The system will also communicate information through a closed network without requiring the Internet. Combining these concepts, this project proposes an advanced solution to house health monitoring.
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

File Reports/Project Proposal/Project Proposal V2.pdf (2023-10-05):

# House Health Monitoring Proposal

Jackson Woodard, Dylan Robbins, Nathaniel Campbell, Luke Carson, Cole Cooper
Electrical and Computer Engineering Department Tennessee Technological University Cookeville, Tennessee
jrwoodard44@tntech.edu, dcrobbins42@tntech.edu, nmcampbell43@tntech.edu, lmcarson43@tntech.edu, cacopper44@tntech.edu
I. INTRODUCTION
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

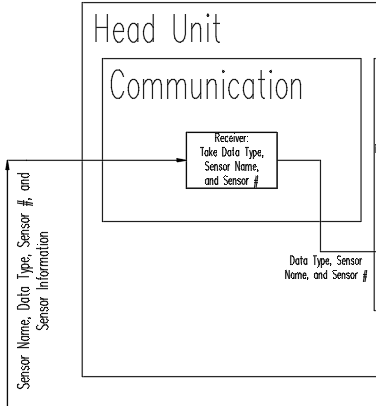
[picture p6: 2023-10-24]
Documentation/Images/Conceptual/ReceiverCommunication.png

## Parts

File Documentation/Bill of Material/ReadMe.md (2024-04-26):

This folder contains the Preserve Home Pro Bill of Material in xslx and pdf form.

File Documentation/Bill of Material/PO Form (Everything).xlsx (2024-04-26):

 | Team Number | Members |  |  |  | Date Submitted to Instructor
Request By: | 4 | Jackson Woodard, Dylan Robbins, Cole Cooper, Luke Carson, Nate Campbell |  |  |  | 2024-02-13
Instructor Signoff:_____________________________________________________________________________________
Part Number | Description | Manufacturer Name | Quantity | URL to Product | Cost per Item | Total cost of Quantity
B07YD2LZDC | Raspberry Pi Power Supply | Seeed Studio (Power Module) | 3 | https://www.amazon.com/Raspberry-Official-Power-Supply-15-3W/dp/B07YD2LZDC | $13.97 | $41.91
DC-14620 | 14.6V Charger LiFePO4 Charger | E-Shark (Power Module) | 1 | https://www.amazon.com/14-6V-Charger-LiFepo4-Battery-li-ion/dp/B09572H8XG | $13.99 | $13.99
HW-4F9 | 12V 9Ah Battery | HWE (Power Module) | 1 | https://www.amazon.com/HWE-Battery-Lithium-Security-Lighting/dp/B0CMTG1M2R | $36.99 | $36.99
L7805CV | L7805 Voltage Regulator | ALLECIN (Power Module) | 1 | https://www.amazon.com/ALLECIN-L7805-Regulator-Positive-Regulators/dp/B0CBKCDT4H?hvadid=409940682138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 | $8.59 | $8.59
1N4001 | 1N4001 Diode | Fairchild Semiconductor (Power Module) | 1 | https://www.amazon.com/FAIRCHILD-SEMICONDUCTOR-1N4001-DIODE-STANDARD/dp/B075SSJQD7?hvadid=580842490296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 | $4.07 | $4.07
C54 | Rain Water Level Sensor | Songhe (Water Module) | 1 | https://www.amazon.com/Sensor-Module-Detection-Surface-Arduino%C3%AF%C2%BC%E2%80%B910pcs%C3%AF%C2%BC%E2%80%BA/dp/B07THDH7Y4 | $6.88 | $6.88
B0B6VR1K5Q | Raspberry Pi 4 Model B | RASTECH (Headunit Module) | 1 | https://www.amazon.com/Raspberry-Quad-core-Cortex-A72-Wireless-Bluetooth/dp/B0B6VR1K5Q?s=electronics | $45.00 | $45.00
B096KDLD4 | 7" 800x400 TFT DSI Touchscreen | WaveShare (Headunit Module) | 1 | https://www.amazon.com/Waveshare-7inch-Capacitive-Resolution-DSI/dp/B096KDLKD4 | $54.90 | $54.90
SDSDQUAN-032G-G4A | Sandisdk Ultra 32GB MicroSD Card | SanDisk (Headunit Module) | 1 | https://www.amazon.com/SanDisk-Ultra-UHS-I-Memory-Adapter/dp/B00M55C0NS | $9.29 | $9.29
SRAQ-G014 | Flammable Gas Sensor | L-COM (Gas Module) | 1 | https://www.l-com.com/flammable-gas-sensor-mq9%3B-co-flammable-gas-analog-ttl-output-sraq-g014 | $7.19 | $7.19
B073Y!J98P | 2700uF 25V Capacitors | Panasonic (Gas Module) | 1 | https://www.amazon.com/pcs-Panasonic-FM-Capacitors-2700uf/dp/B073YQJ98P | $16.99 | $16.99
DZ-ZCDZ2WB1-1R-30 | 30pk 2W 1 Ohm Resistor | Chanzon (Gas Module) | 1 | https://www.amazon.com/Resistor-Tolerance-Resistors-Limiting-Certificated/dp/B08QR6WKMY | $5.99 | $5.99
ST-PROTO | Double Sided ENIG Solderable Breadboard | SchmalzTech (Gas Module) | 3 | https://www.amazon.com/SchmalzTech-Protoboard-Solderable-Breadboard-Electronic/dp/B0C4HW97V7 | $3.99 | $11.97
SRAQ-GO16 | Ammonia Gas Sensor | L-COM (Gas Module) | 1 | https://www.l-com.com/ammonia-nh3-sensormq135-sraq-g016 | $18.99 | $18.99
3-01-1294 | HiLetgo MLX90614ESF | HiLetgo (Fire Module) | 1 | https://www.amazon.com/HiLetgo-MLX90614ESF-Non-contact-Infrared-Temperature/dp/B071VF2RWM | $15.99 | $15.99
B07GD2BWPY | 120pc Breadboard Jumpers | EDGELEC (Fire Module) | 1 | https://www.amazon.com/EDGELEC-Breadboard-Optional-Assorted-Multicolored/dp/B07GD2BWPY | $6.98 | $6.98
ESP32-H2-DEVKITM-1-N4 | ESP32-H ESP32-H2-MINI-1 Transceiver; 802.15.4 (ZigBee®), Bluetooth® Smart 4.x Low Energy (BLE) Evaluation Board | Espressif Systems (Communication Module) | 3 | https://www.digikey.com/en/products/detail/espressif-systems/ESP32-H2-DEVKITM-1-N4/18109238 | $10.00 | $30.00
XB24CAWIT-001 | Zigbee Modules - 802.15.4 XBee, S2C, 2.4GHz Through-hole,Wireant | DIGI (Communication Module) | 1 | https://www.mouser.com/ProductDetail/DIGI/XB24CAWIT-001?qs=%2FPVulymFwT1u0cCwuRVF0g%3D%3D&mgh=1 | $30.67 | $30.67
B09JVSN8GF | DUNSI Sht30 Temperature Humidity Sensor Module- Temperature Sensor Sht30 Profional Temperature Humidity Censation Probe Sensor I2C Interface with Shell for Iic Digital Signal 0-100% Rh | DUNSI (Communication Module) | 1 | https://www.amazon.com/Temperature-Humidity-Profional-Censation-Interface/dp/B09JVSN8GF | $9.99 | $9.99
 |  |  | 25 |  |  | $376.38

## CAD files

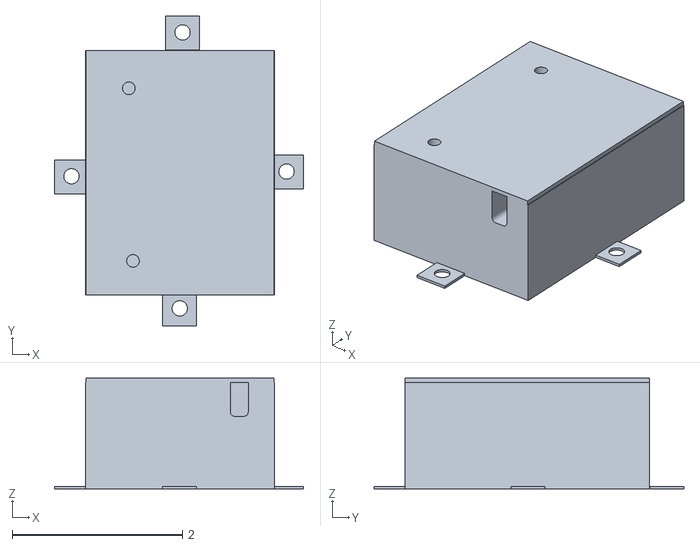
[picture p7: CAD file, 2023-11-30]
Documentation/3D Models/Fire Module/FireModuleEnclosure.stl
2.93 x 3.64 x 1.30

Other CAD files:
Documentation/3D Models/Fire Module/FireModuleEnclosure.dwg

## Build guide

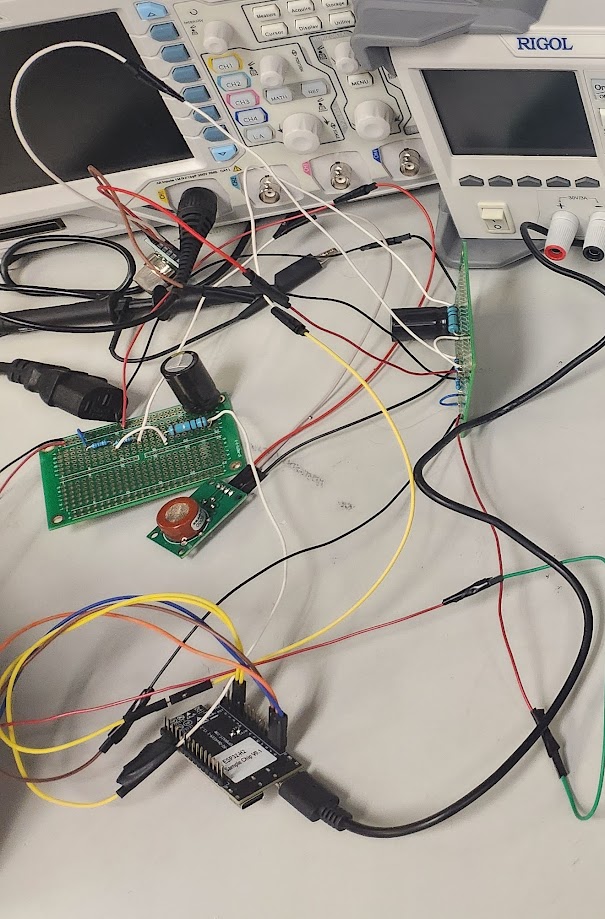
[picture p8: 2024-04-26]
Documentation/Images/Gas/Gas_Assembled_Circuit.png

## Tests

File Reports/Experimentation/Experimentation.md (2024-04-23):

# Experimental Analysis Report

## Introduction
The purpose of this report is to show the experimentation, results, and interpretation of results for each module. These results will then be compared to our constraints and measures of success in ordere to determine if each module has been implemented successfully. Each set of constraint is seperated by their associated module. 

Click to go to [Head Unit](#head-unit) experimentation. <br/>
Click to go to [Communication](#communication) experimentation. <br/>
Click to go to [Flood](#flood) experimentation. <br/>
Click to go to [Gas](#gas) experimentation. <br/>
Click to go to [Fire](#fire) experimentation. <br/>
Click to go to [Mold](#mold) experimentation. <br/>
Click to go to [Power](#power) experimentation. <br/>

## Specifications and Constraints

### Table of Constraints
| **No.** | **Constraints** | **Origin** |
| :--: | :-- | :--: |
|  |  |  |
| -- | **Head Unit** | -- |
|  |  |  |
|  1  | The head unit shall know what sensor is sending data to it, the sensors location, and be able to differentiate from other sensors. | Team Supervisor & Project Team |
|  2  | The head unit shall be able to display and log active and historical data from sensors. | Project Team & Team Supervisor |
|  3  | The head unit shall be able to detect if the fire module temperature is at 176&#176; Fahrenheit or higher and display a warning. | Project Team |
|  4  | The head unit shall be able to receive data from the water module to display a warning if water is present and the total water depth. | Project Team |
|  5  | The head unit shall be able to receive data and follow OSHA standards for ammonia, propane, and carbon oxides (50 ppm, 1000 ppm, and 50 ppm respectively over an eight hour window). | Standards & Project Team |
|  6  | The head unit shall be able to interpret, from the received data, that mold could form if the humidity levels exceed 50% and temperatures range between 55&#176; and 85&#176; Fahrenheit for a minimum of two days. | Project Team |
|  |  |  |
| -- |  **Communication**  |  --  |
|  |  |  |
|  1  | System shall not require an internet connection to work and communicate with the head unit and sensors. | Home Owners, Insurance Agencies, & Team Supervisor |
|  2  | At least one sensor shall be placed within 200ft of the head unit. | Project Team |
|  3  | Sensors shall be within 32ft from each other for every sensor outside of 200ft of the head unit. | Project Team |
|  4  | Sensor communication shall send the sensor name, number, data type, and raw data to the head unit. | Project Team |
|  5  | ESP32 shall be able to send a minimum of 128 bits (2 packets) at a transmission rate of at most 250 Kbps on a 2.4 GHz frequency. | Project Team & Standards|
|  6  | The head unit shall, at minimum, receive data every 24 hours, when the data from the sensor reaches a critical level, or when the user requests the data. | Project Team |
|  |  |  |
| -- |  **Flood**  |  --  |
|  |  |  |
|  1  | Sensor shall be able to detect if at least one inch of water is present in a room. | Project Team & Broader Implications |
|  2  | Sensors shall be able to detect water levels at various depths.| Project Team |
|  3  | Sensor shall send data to headunit in seconds if water is detected.| Project Team |
|  4  | Sensor shall be placed in areas flooding is most likely to occur. | Project Team |
|  5  | Sensor shall not be placed in areas where condensation can't easily form. | Broader Implications |
|  |  |  |
| -- |  **Gas**  |  --  |
|  |  |  |
|  1  | The Gas module shall be able to detect ammonia, propane, and carbon oxide. | Project  Team, Insurance Agencies|
|  2  | Head unit shall receive data from the gas module and follow OSHA standards for ammonia, propane, and carbon oxides (50 ppm, 1000 ppm, and 50 ppm respectively over an eight-hour window).| OSHA |
|  3  | The Gas module shall send data to headunit every second if the targeted gases are detected. | Project Team |
|  4  | The Gas module shall be installed in a central location outside each sleeping area or in the immediate vicinity of the bedrooms, at the maximum of 20 feet. | NFPA |
|  5  | The Gas module shall be placed as close as possible to potential gas leak spots. | Project Team, Existing Products |
|  6  | The Gas module shall be orientated to where the target gas vapours tend to rise or fall. | Project Team, Existing Produts |
|  7  | The Gas module shall not be placed near entrances/disturbances or fresh air vents where concentrations can be diluted. | Project Team, Existing Products |
|  8  | The Gas module shall not be placed in bathrooms, garages, kitchens, furnace rooms, extremely dusty or dirty areas. | Project Team, Existing Products |
|  9  | The Gas module shall not be placed in areas of the house enviroment where it is colder than -10°C or hotter than 50°C. | Manufacturer |
|  10  | The Gas module shall not be placed in areas of the house enviroment where the humidity is more than 95%. | Manufacturer |
|  11  | The Gas module shall be protected from unwanted variation of sensor readings due to noise. | Project Team |
|  |  |  |
| -- |  **Fire**  |  --  |
|  |  |  |
|  1  | Shall be able to detect the minimum temperature of 176&deg; Fahrenheit. | Project Team |
|  2  | Shall send sensor data to the ESP32 every second. | Project Team |
|  3  | Shall send temperature data to the head unit if 176&deg; Fahrenheit has been reached. | Project Team |
|  4  | Shall not be a distraction to the homeowner. | All External Stakeholders, Ethics, & Team Supervisor |
|  |  |  |
| -- |  **Mold**  |  --  |
|  |  |  |
|  1  | Shall be able to detect temperature ranges between 55&deg; F - 85&deg; F and humidity levels exceeding 50% RH. | Project Team |
|  2  | Shall be able to communicate through I2C protocol and send data once every hour to its local ESP32-H2 transmitter, then enter sleep mode until the next hour. | Project Team |
|  3  | Shall be protected and not exposed to harsh environmental conditions to prevent any damage to the sensor. | All External Stakeholders, Ethics, & Team Supervisor |
|  4  | Shall give precise temperature and humidity readings within 0.5&deg; F and 2% RH of the actual values, rounding to the nearest whole number to properly evaluate and determine if mold like conditions are present. | Project Team |
|  |  |  |
| -- |  **Power**  |  --  |
|  |  |  |
|  1  | System shall be primarily powered from the house's 120 Volt power supply. | Project Team |
|  2  | Shall have a backup power system that will allow the system to function in case of primary power outage for up to two continuous weeks. | Project Team & Team Supervisor |
|  3  | Shall fully function without regularly changing sensors or head unit batteries. | All External Stakeholders, & Team Supervisor |

## Experimental Results

### Head Unit
#### Constraint 1 - The head unit shall know what sensor is sending data to it, the sensors location, and be able to differentiate from other sensors.
-Experimental Design: To test this constraint, the team each sensor to the head unit in different orders in order to assure the sensors were connecting and outputting the expected information.

-Results: In the set of 5 trials, the head unit was able to successfully connect to each sensor connected without losing connection to previously connected sensors. Below are pictures of the first series of connections with a table showing the results from the overall trials.







| Sensor Name | Sensor Connection to Head Unit | Number of Sensors Connected |
| :--: | :--: | :--: |
| **Order 1** | | |
| Fire Temperature | Yes | 1 |
| Mold Temperature | Yes | 2 |
| Mold Humidity | Yes | 3 |
| Flood | Yes | 4 |
| Gas Ammonia | Yes | 5 |
| Gas LPG & CO | Yes | 6 |
| **Order 2** | | |
| Gas LPG & CO | Yes | 1 |
| Gas Ammonia | Yes | 2 |
| Flood | Yes | 3 |
| Mold Humidity | Yes | 4 |
| Mold Temperature | Yes | 5 |
| Fire Temperature | Yes | 6 |
| **Order 3** | | |
| Flood | Yes | 1 |
| Fire Temperature | Yes | 2 |
| Mold Temperature | Yes | 3 |
| Mold Humidity | Yes | 4 |
| Gas Ammonia | Yes | 5 |
| Gas LPG & CO | Yes | 6 |
| **Order 4** | | |
| Mold Temperature | Yes | 1 |
| Mold Humidity | Yes | 2 |
| Gas LPG & CO | Yes | 3 |
| Gas Ammonia | Yes | 4 |
| Fire Temperature | Yes | 5 |
| Flood | Yes | 6 |
| **Order 5** | | |
| Fire Temperature | Yes | 1 |
| Flood | Yes | 2 |
| Gas LPG & CO | Yes | 3 |
| Gas Ammonia | Yes | 4 |
| Mold Temperature | Yes | 5 |
| Mold Humidity | Yes | 6 |

-Interpretation: The head unit is able to determine what sensor is sending data to it and differentiate it from other sensors. The sensor location had to be input into Home Assistant after the sensors were connected.

#### Constraint 2 - The head unit shall be able to display and log active and historical data from sensors.
-Experimental Design: To test this constraint, the head unit recoded each module from an 8 to 24 hour period in order to ensure that the head unit is able to record data from each sensor. 

-Results: The head unit was able to receive, store, and displat the information from the fire module over the tested 24 hour period.


The head unit was able to receive, store, and display information from the mold module over in the 8 hour period tested.


The head unit was able to receive, store, and display the information from the flood module over the tested 8 hour period.


The head unit was able to receive, store, and display information from the gas module during the 11 hour period tested. 


This is the view that the head unit has for live reading of the sensor modules.

-Interpretation: The head unit is able to store and display data for active and historical readings.

#### Constraint 3 - The head unit shall be able to detect if the fire module temperature is at 176&#176; Fahrenheit or higher and display a warning.
-Experimental Design: To test this constraint, the team used the fire temperature sensor and an ignited lighter next to it and recorded the data 5 times. This test shows whether or not the head unit is able to record the temperatures recorded by the sensor and give a warning if the temperature is at or above 176&deg;F.

-Results: The team expected the results to display a warning if a temperature of 176&deg;F or higher is reached. Shown below is the head unit's logging of the temperatures when a lighter is present.

FireSensor176Plus



-Interpretation: The head unit was able to read and display readings of 176&deg;F and higher with a warning for potential fire.

#### Constraint 4 - The head unit shall be able to receive data from the water module to display a warning if water is present and the total water depth.
-Experimental Design: To test this constraint the team placed the water sensor in a cup of water to see if the head unit recorded the depth of the water with a warning that water is present. This experiment was repeated seven times.





-Interpretation: The head unit was able to detect if water was present, show its depth, and give a warning that water was present.

#### Constraint 5 - The head unit shall be able to receive data and follow OSHA standards for ammonia, propane, and carbon oxides.
-Experimental Design: For this experiment, the sensors would sense the gases and the data would be sent to the ESP32-H2 ADC and from there Preserve Home Pro coded the microcontrollers to make sure the gas levels stayed under those levels specified in the constraint previously for the eight hour window.

-Results: Due to the necesity of dangerous gases in order to fully test this functionality, Preserve Home Pro did not test this feature.

-Interpretation: Based on the sensor datasheets, Preserve Home Pro would be able to code the sensor's in order to work together and be able to maintain that data information so that constraint can be met. 

#### Constraint 6 - The head unit shall be able to interpret, from the received data, that mold could form if the humidity levels exceed 50% and temperatures range between 55&#176; and 85&#176; Fahrenheit for a minimum of two days.
-Experimental Design: For this experiment, the team used a steam gun to raise the temperature and humidity next to the mold module 5 times to see if the head unit will be able to flag that the humidity over 50 % and a temperature over 55&#176 Fahrenheit. 

-Results: The head unit read the raises in temperature and humidity and output a warning that mold is possible. 



-Interpretation: The head unit is able to determine if the values from the mold module are conducive for the growth of mold. 

### Communication
#### Constraint 1 - System shall not require an internet connection to work and communicate with the head unit and sensors.
-Experimental Design: The sensors and head unit communicate via Zigbee Communication.

-Results: The head unit and sensors successfully paired and transmit data using the Zigbee Communication Standard IEEE 802.15.4.

-Interpretation: The head unit and sensors are able to communicate and work without an internet connection.

#### Constraint 2 - At least one sensor shall be placed within 200ft of the head unit.
-Experimental Design: To test this the team took a sensor module into the hallway and walked 100 ft. down the hall and checking if the head unit is still receiving updates from the mold module.

-Results: The head unit and mold module were able to continue communication every 2 to 5 seconds at 50 ft. line of sight, 50 ft. through two cinder block walls, and 100 ft. through 2 cinder block walls over three sets of trial. 





-Interpretation: The head unit is able to communicate with a sensor module through cinder block walls within the tested 100 ft. range. 

#### Constraint 3 - Sensors shall be within 32ft from each other for every sensor outside of 200ft of the head unit.
-Experimental Design: Each module should be within 32ft so the Zigbee mesh can connect different modules together for communication with the head unit. 

-Results: When the sensor modules are within the 32 ft range of each other, they are able to establish the Zigbee mesh needed for communication of sensor modules to the head unit. 

-Interpretation: The Zigbee network is functioning as expected. 

#### Constraint 4 - Sensor communication shall send the sensor name, number, data type, and raw data to the head unit.
-Experimental Design: To test this constraint, the team each sensor to the head unit in different orders in order to assure the sensors were connecting to the head unit, identified by their names, showing what type of data it was sharing, and outputting values.

-Results: In the set of 5 trials, the head unit was able to successfully connect to each sensor connected without losing connection to previously connected sensors. Below are pictures of the first series of connections with a table showing the results from the overall trials. 







| Sensor Name | Sensor Connection to Head Unit | Number of Sensors Connected |
| :--: | :--: | :--: |
| **Order 1** | | |
| Fire Temperature | Yes | 1 |
| Mold Temperature | Yes | 2 |
| Mold Humidity | Yes | 3 |
| Flood | Yes | 4 |
| Gas Ammonia | Yes | 5 |
| Gas LPG & CO | Yes | 6 |
| **Order 2** | | |
| Gas LPG & CO | Yes | 1 |
| Gas Ammonia | Yes | 2 |
| Flood | Yes | 3 |
| Mold Humidity | Yes | 4 |
| Mold Temperature | Yes | 5 |
| Fire Temperature | Yes | 6 |
| **Order 3** | | |
| Flood | Yes | 1 |
| Fire Temperature | Yes | 2 |
| Mold Temperature | Yes | 3 |
| Mold Humidity | Yes | 4 |
| Gas Ammonia | Yes | 5 |
| Gas LPG & CO | Yes | 6 |
| **Order 4** | | |
| Mold Temperature | Yes | 1 |
| Mold Humidity | Yes | 2 |
| Gas LPG & CO | Yes | 3 |
| Gas Ammonia | Yes | 4 |
| Fire Temperature | Yes | 5 |
| Flood | Yes | 6 |
| **Order 5** | | |
| Fire Temperature | Yes | 1 |
| Flood | Yes | 2 |
| Gas LPG & CO | Yes | 3 |
| Gas Ammonia | Yes | 4 |
| Mold Temperature | Yes | 5 |
| Mold Humidity | Yes | 6 |

-Interpretation: The head unit is able to determine what sensor is sending data to it and differentiate it from other sensors. The sensor location had to be input into Home Assistant after the sensors were connected.

#### Constraint 5 - ESP32 shall be able to send a minimum of 128 bits (2 packets) at a transmission rate of at most 250 Kbps on a 2.4 GHz frequency.
-Experimental Design: This constraint is a Zigbee requirement for communication of sensors in a Zigbee Mesh Network. 

-Results: All sensor modules and the head unit use Zigbee certified transmitters and receivers.

-Interpretation: The system is able to correctly communicate using Zigbee communication. 

#### Constraint 6 - The head unit shall, at minimum, receive data every 24 hours, when the data from the sensor reaches a critical level, or when the user requests the data.
-Experimental Design: The team tested this constraint by monitoring the sensor readings over periods of time ranging from 8 to 24 hours to make sure each sensor updates at least once in the period tested. 

-Results: The head unit was able to receive and store information from the fire more than once within the minimum 24 hour period


The head unit was able to receive and store information from the mold module more than once in the 8 hour period.


The head unit was able to receive ans store information from the flood module more than once in the tested 8 hour period.


The head unit was able to receive and store information from the gas module at least one time in the 11 hour period. 


-Interpretation: The modules are able to communicate more often than the minimum specification of once every 24 hours.

### Flood
#### Constraint 1 and 2 - Sensor shall be able to detect if at least one inch of water is present in a room and Sensors shall be able to detect water levels at various depths.
-Experimental Design: To test these contrtaints, the sensor was measured with a ruler and marked at .5, 1, and 1.5 inches and put into a container of water that had a depth of 1.5 inches. 



-Results: Screenshot 2024-04-17 at 12 50 48 PM

-Interpretation: Originally the sensor was marked every quarter inch. This did not give the expected results as the readings were very inconsitent. The markings and code were changed to every half inch to provide more accurate readings of a half inch, one inch, and 1.5 inch. As shown in the results the water sensor can measure different depths roughly with 0, .5, 1, and 1.5 inches. For future improvements, a more accurate sensor will be chosen. 

#### Constraint 3 - Sensor shall send data to headunit in seconds if water is detected.
-Experimental Design: To adhere to this constraint, the sensor was coded to send data every two seconds.

-Results:Screenshot 2024-04-16 at 12 15 03 PM

-Interpretation: In its current state the sensor checks for changes every two seconds. As shown from the chart there is updates every two seconds as water levels change followed by a periods of no change when the sensor is dry.
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

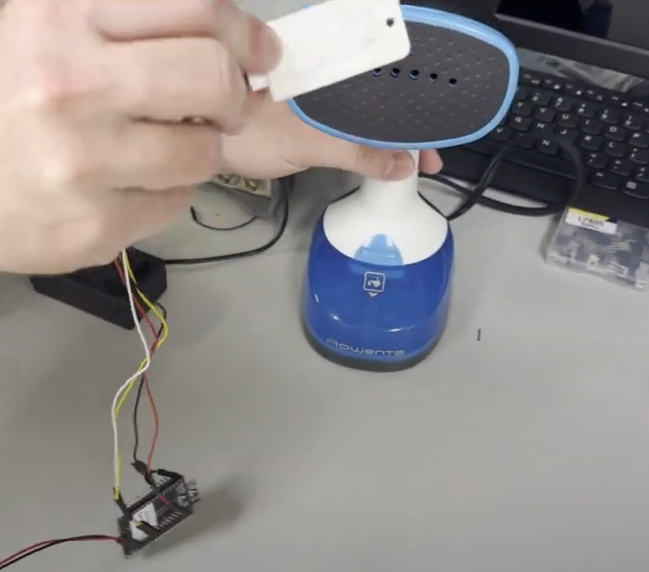
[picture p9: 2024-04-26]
Documentation/Images/Mold/Mold_Test.PNG

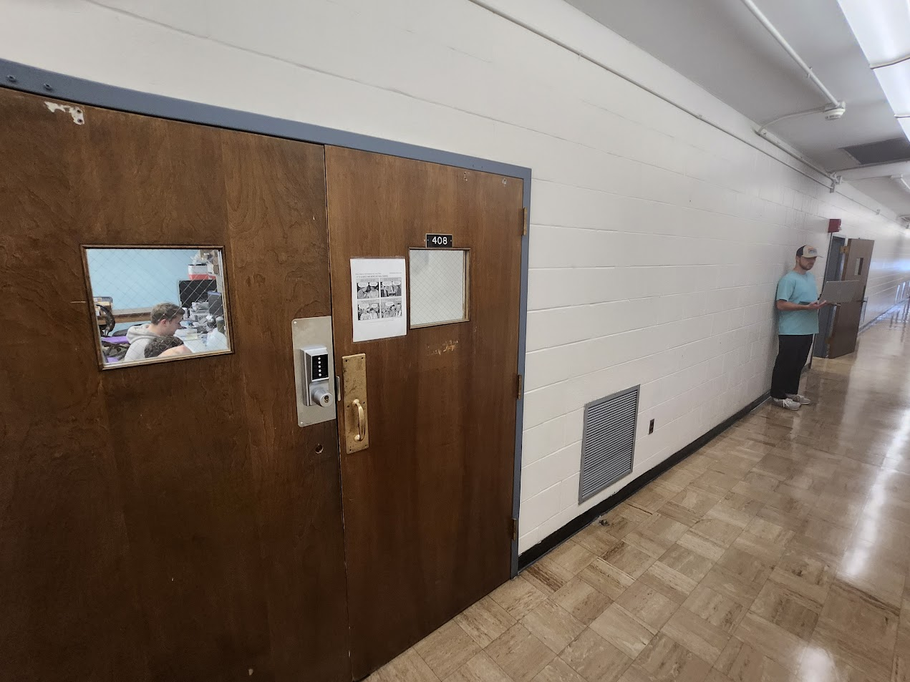
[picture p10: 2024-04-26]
Documentation/Images/Communication/Communication_Test_50ft_with_walls.png

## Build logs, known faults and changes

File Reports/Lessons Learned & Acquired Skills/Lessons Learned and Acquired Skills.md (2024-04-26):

# Lessons Learned

- Reflect on the project, both technical and organizational. What went well? What didn’t go well? 
- What unanticipated problems occurred? 
- What would you do differently if you were to do it over again? 
- What “best practices” have you identified? 
- What words of wisdom would you pass on to future students?
- What new knowledge or skills did you acquire throughout capstone.

## Jackson Woodard
- My expectations for this project were pretty high because I always set high standard for myself. At the beginning of capstone two, I was so stressed and assuming that we would not be able to get it working. After a month or two of trial and error in coding, we finally got it working and it was the greatest feeling. The group did really well with communication and we had meetings multiple times a week to complete our project.

- I thought we would be able to use Arduino IDE for the entire project, but I was completly wrong. We had to learn how to code with ESP-IDF in VSCode, and that took some time. I figured it would be easy to use the sensor libraries, but once again, I was wrong. We had to code the sensors from scratch with no libraries and that was tough, but we got it done.

- Even though we were on campus everyday 4-5 hours outside of class, I would have like to have the project done sooner so we could have got a better grade. Taking capstone two while full time in school is the most time consuming thing I have ever done, so if I could go back and change something, it would be spending even more time working on this project.

- I would say my public speaking skills have increased in this class due to the amount of speaking we have to do infront of people. I would also say I have a better understanding of understanding what a customer wants and be able to get the information from them about what they want if they do not provide enough.

- Be ready to devote your entire semester to capstone because if you do not, it will be hard to make a good grade and complete everything on time. Take everything a step at a time because it is very very easy to get overwhelmed very quickly.

- I learned more in capstone then I learned in any class I took in college. The amount of research and trial and error in this class tought me how to properly do research, how to code alot more effectively, and how to work better and effectively with a team.

## Nate Campbell
- I honestly didn't know what to expect going into capstone. However, after months of persistent coding and teamwork, we achieved success, which was incredibly satisfying. Our group's communication and persistence was excellent, with frequent meetings helping us stay on track and complete our project efficiently. What didnt go as well would be the sheer amount of time we spent each day working on the project.

- Some unanticipated problems would be just trying to integrate zigbee communication. I personally thought the process would be a little more straightforward.
  
- If i could change anything I would have put more effort into the communication subsystem upfront and make sure it was ready to go before the other subsystems.

- Documenting everything and having a reason for why everything is done the way we did. Being able to take a third party perspective on the entire project.
  
- To not get lost in the grades and not lose sight of the end goal.

- How to build a proper project from beginning to end. It required extensive research and critical thinking. It also allowed me to really see ways of thinking from different perspectives.

## Cole Cooper
- The biggest technical failure the team had was the XBee S2C not functioning as intended. We found out after already having the unit and setting it up that it would not communicate with the ESP32 H2, Raspberry Pi 4B, and a spare Arduino Mega 2560. The team ended up buying the Sonoff USB 3.0 Zigbee coordinator dongle that worked exactly as expected when connected to the head unit. The sensors’ communication to the ESP32s went very smoothly using the Arduino IDE with the ESP IDF but the Zigbee communication would not work until the Arduino libraries were converted over to the Visual Studio Code IDE with the ESP IDF. Organization wise, the team worked well together with a lot of communication between members over the successes and holdups experienced. 

- The largest unanticipated problem was figuring out how to code the ESP32 H2s to communicate via Zigbee protocols. We expected this to be difficult but not to take up about two months of the project’s time. Eventually the team did overcome these obstacles, but it took a lot of trial and error to achieve this success. 

- If I were to do something differently it would be to use different microcontrollers for the sensor modules. The ESP32 H2s used are fantastic hardware, but they are still quite new and do not have a lot of example codes which makes it much more difficult to design custom solutions using the microcontroller. Other ESP devices are easier to work with since they do have more example codes to work with.

- The primary best practice I identified is researching if codes exist for the hardware that is planning on being used. Researching forums, github repositories, and manufacturer documents to ensure that the intended application is possible and achievable within the six month time period demanded by this course.

- Make sure to check all of the grading rubrics before starting and while making your “Project Proposal” and “Conceptual Design & Planning” documents. The Project Proposal is what you are doing, like declaring your standards and constraints. Be aware of how you can solve what you are doing, but do not actually go into depth with how to solve your issues until you get to the Conceptual Design & Planning phase. This class is very similar to the stricter side of engineering work experience that I have worked with in the past, a lot of points may seem overly strict or unnecessary, but if you can figure out how to work within the rules given this class gets a lot more straightforward. 

- Team building, communication, patience, coding, experimenting, and proving that a system will work beyond what a manufacturer claims are a few of the experiences that this class has given me. I have a decent amount of experience with the stuff mentioned from previous engineering and non-engineering work experiences, but even so I feel the challenges and overcoming of those challenges has been a good experience.

## Luke Carson
- From start to finish the project was a series of obstacles. At times it was overwhelming and frustrating. Once, the group or even yourself got over a obstacle you felt a sign relief but you had to be looking ahead and staying on task in order to meet your deadlines. Overall, this course does teach you skills that will translate into your future job like documentation, communication, teamwork, and accountability. 

- Definitely the coding of our sensors was the biggest anticipation of the group. In your head you feel like you have it all planned out and this is going to work like this and sadly that was not the case for our communication module. Instead of using arduino IDE, we had to implement ESP-IDF which I think any of us had previous experience with unlike arduino IDE. So, we had to learn on the fly and watch alot of youtube and research alot more than intended.

- Even though we already spent countless hours on our capstone project, it just felt like we still needed more time to really accomplish what we set out to do. But time is a constraint and you have to manage with what you are given.

- Researching is very helpful and being able to look at datasheets to see if the product is going to meet your desired needs is a big thing. Also, communication with your team is another big practice because of the aspect of everyone is on the same page or even you need some help with your system you always got another mind there for your benefit.

- Time management is going to be your biggest friend and enemy. The project will eat up alot of your time during the semester with signoffs being checked off or even experimentation testing. Luckily, I only had 6 hours this semester so I could almost fully commit to our project, but if that was a different scenario I could see myself under alot of stress.

- Literally taking everything I learned in undergrad and being able to tie everything in together with one big project. Also, I felt like this class helped with my public speaking skills as well. 

## Dylan Robbins
- Going into Capstone, I was expecting the course to be just like any other course except strictly focused on the process of design and being hands on with things. I was right about most of it, but I had no idea that it was going to consume so much of my time. I learned that being proactive and having great communication with your team are two of the most important things for success throughout this course. Our team had a lot of success with our project, but the implementation of the communication set us back quite a bit. We spent maybe a month or longer trying to code for our modules to be able to communicate with each other. I believe that without the relationship and communication we all had the project might not have gotten finished.

- Touching back on my first point, coding for wireless communication was the biggest unanticipated problem we encountered. At first, we were on track to have everything finished up well before the deadline, but after days upon days trying to figure out the communication code, we were not getting anywhere. We ended up having to swap coordinator devices and digging deep into a lot of example codes to get the issue resolved. We learned a lot of new things on our own through research and trial and error.

- If I were to do something differently, I would have tried my best to understand the full implementation of the system and pieces needed from the start. Not knowing exactly what was expected of us with the communication module was rough when we finally got to it. I think it would have been nice to do a little more research and understand how to implement the communication before we bought a device and wasted a bunch of time on it.

- I would say that some of the best practices would be to stay proactive and have great communication with your team. Making sure everyone stays involved in research so they know what is going on will benefit everyone in the long run.

- Stay proactive and start immediately. Do not think that a due date being a month out is plenty of time to get things done. This course is very intensive so expect to spend a lot of time with your group and in the lab if you want to make a good grade.

- I believe that my research, problem solving, and analysis skills greatly improved over the course of capstone. To be honest, not many classes will prepare you for the work in this course. I had to spend countless hours trying to figure things out on my own and doing my own research to learn new things. In the end, it pays off because it has prepared me a little more for what to expect in the real world.

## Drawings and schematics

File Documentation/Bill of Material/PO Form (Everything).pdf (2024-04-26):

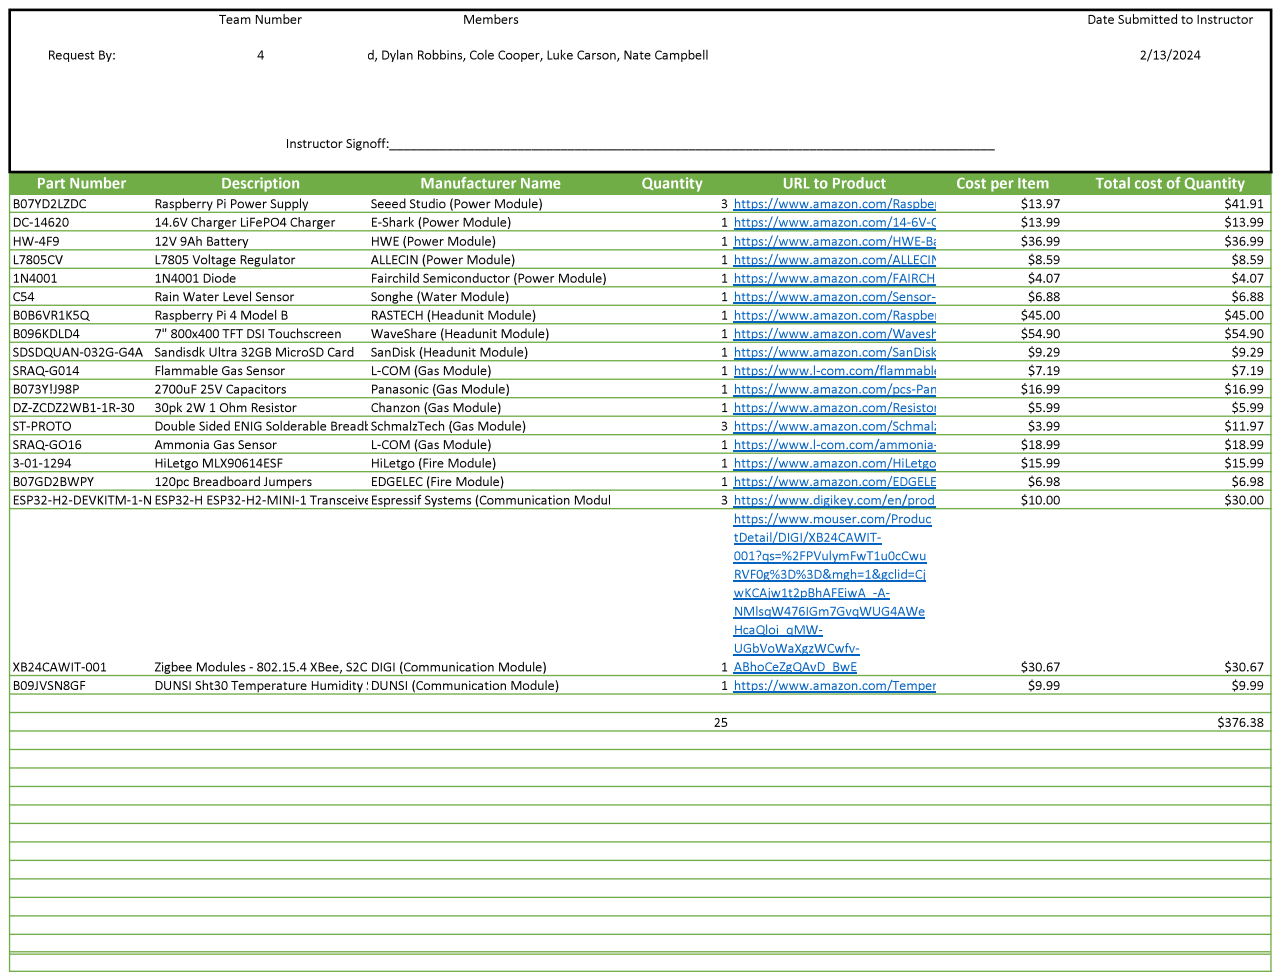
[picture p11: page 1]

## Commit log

2023-11-01 formatted colecooper-power-signoff.md
2023-11-29 took out the reference to wireless communication
2024-02-06 Requesting Power Module Signoff
2024-02-19 Update colecooper-power-signoff.md
    updated source
